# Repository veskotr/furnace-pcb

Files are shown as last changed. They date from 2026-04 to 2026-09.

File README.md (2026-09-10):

# Furnace Controller PCB

Hardware revisions are kept side by side:

- `Furnace_Controller_V1/` — the original 99-footprint design, last produced in June 2026.
- `Furnace_Controller_V2/` — the active 125-footprint revision, including the expanded functional-sheet hierarchy and TI footprint corrections.

Open the `Furnace_Controller.kicad_pro` inside the revision you intend to edit.
Shared third-party symbols and footprints live in `libraries/Symbols/`; each revision's
library-table files resolve these assets using project-relative paths.

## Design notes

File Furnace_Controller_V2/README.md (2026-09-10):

# Furnace Controller V2

Open `Furnace_Controller.kicad_pro` as the project entry point.

The root schematic is the system sheet. Functional sheets are named by their
role (power conversion, communications, supervision, I/O, Ethernet, and relay
drivers). Repeated relay and 3.3 V regulator channels intentionally share a
single child-sheet source.

Project-local TI symbols and footprints are declared in `sym-lib-table` and
`fp-lib-table`; their source files live in `../libraries/Symbols/`. Child
schematics live in `sheets/`; generated Gerbers and assembly outputs live in
`fabrication/`, while PDFs and 3D exports live in `documentation/`.

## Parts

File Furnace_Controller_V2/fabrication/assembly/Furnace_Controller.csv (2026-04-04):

Reference | Qty | Value | DNP | Exclude from BOM | Exclude from Board | Footprint | Datasheet
BZ1 | 1 | Buzzer |  |  |  | Buzzer_Beeper:Buzzer_15x7.5RM7.6 | ~
C1 | 1 | 220u |  |  |  | Capacitor_THT:CP_Radial_D12.5mm_P5.00mm | ~
C2,C5,C6,C7,C8,C9 | 6 | 100n |  |  |  | Capacitor_SMD:C_0805_2012Metric_Pad1.18x1.45mm_HandSolder | ~
C3 | 1 | 47u |  |  |  | Capacitor_THT:CP_Radial_D8.0mm_P2.50mm | ~
C4,C10 | 2 | 10u |  |  |  | Capacitor_THT:CP_Radial_D5.0mm_P2.00mm | ~
D1,D16 | 2 | 1N5822 |  |  |  | Diode_THT:D_DO-201AD_P15.24mm_Horizontal | http://www.vishay.com/docs/88526/1n5820.pdf
D2,D4,D7,D9,D19 | 5 | 1N4148 |  |  |  | Diode_THT:D_DO-35_SOD27_P7.62mm_Horizontal | https://assets.nexperia.com/documents/data-sheet/1N4148_1N4448.pdf
D3,D5,D6,D8,D10,D11,D12,D13,D14,D15 | 10 | LED |  |  |  | LED_SMD:LED_0805_2012Metric | ~
D17,D18 | 2 | SMAJ30CA |  |  |  | Diode_SMD:D_SMA | https://www.littelfuse.com/media?itemid=75e32973-b177-4ee3-a0ff-cedaf1abdb93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
F2 | 1 | 3588 |  |  |  | MiniAutoFuse:3588 | https://www.keyelco.com/product-pdf.cfm?p=311
H1,H2,H3,H4 | 4 | MountingHole |  | Excluded from BOM |  | MountingHole:MountingHole_5.3mm_M5 | ~
J1 | 1 | Power In Treminal |  |  |  | TerminalBlock:TerminalBlock_MaiXu_MX126-5.0-02P_1x02_P5.00mm | ~
J3 | 1 | Relay Terminal |  |  |  | TerminalBlock:TerminalBlock_MaiXu_MX126-5.0-09P_1x09_P5.00mm | ~
J4 | 1 | HMD Terminal |  |  |  | TerminalBlock:TerminalBlock_MaiXu_MX126-5.0-04P_1x04_P5.00mm | ~
J5 | 1 | RS-485 Terminal |  |  |  | TerminalBlock:TerminalBlock_MaiXu_MX126-5.0-04P_1x04_P5.00mm | ~
L1 | 1 | 33u |  |  |  | Coil:SRR1260-150M | ~
Q1,Q2,Q3,Q4 | 4 | IRLZ44N |  |  |  | Package_TO_SOT_THT:TO-220-3_Vertical | http://www.irf.com/product-info/datasheets/data/irlz44n.pdf
Q5 | 1 | 2n2222 |  |  |  | Package_TO_SOT_THT:TO-92_Inline | https://diotec.com/tl_files/diotec/files/pdf/datasheets/bc337.pdf
R1,R3 | 2 | 10k |  |  |  | Resistor_SMD:R_0805_2012Metric_Pad1.20x1.40mm_HandSolder | ~
R4,R7,R10,R14 | 4 | 100 |  |  |  | Resistor_SMD:R_0805_2012Metric_Pad1.20x1.40mm_HandSolder | ~
R5,R8,R11,R15 | 4 | 47k |  |  |  | Resistor_SMD:R_0805_2012Metric_Pad1.20x1.40mm_HandSolder | ~
R6,R9,R12,R13,R18,R19,R21,R22 | 8 | 68 |  |  |  | Resistor_SMD:R_0805_2012Metric_Pad1.20x1.40mm_HandSolder | ~
R16,R17 | 2 | 15 |  |  |  | Resistor_SMD:R_0805_2012Metric_Pad1.20x1.40mm_HandSolder | ~
R20,R23 | 2 | 330 |  |  |  | Resistor_SMD:R_0805_2012Metric_Pad1.20x1.40mm_HandSolder | ~
R24 | 1 | 120 |  |  |  | Resistor_SMD:R_0805_2012Metric_Pad1.20x1.40mm_HandSolder | ~
R25 | 1 | 1k |  |  |  | Resistor_SMD:R_0805_2012Metric_Pad1.20x1.40mm_HandSolder | ~
TP1,TP3,TP4,TP6 | 4 | HR_TP |  |  |  | TestPoint:TestPoint_Pad_D1.5mm | ~
TP2 | 1 | PGND_TP |  |  |  | TestPoint:TestPoint_Pad_D1.5mm | ~
TP5,TP7,TP8,TP9,TP11 | 5 | LGND_TP |  |  |  | TestPoint:TestPoint_Pad_D1.5mm | ~
TP12 | 1 | RSB_TP |  |  |  | TestPoint:TestPoint_Pad_D1.5mm | ~
TP13 | 1 | RSA_TP |  |  |  | TestPoint:TestPoint_Pad_D1.5mm | ~
TP14,TP20 | 2 | 5V_TP |  |  |  | TestPoint:TestPoint_Pad_D1.5mm | ~
TP15 | 1 | U2RX_TP |  |  |  | TestPoint:TestPoint_Pad_D1.5mm | ~
TP16 | 1 | U2TX_TP |  |  |  | TestPoint:TestPoint_Pad_D1.5mm | ~
TP18 | 1 | RS_DIR |  |  |  | TestPoint:TestPoint_Pad_D1.5mm | ~
TP19,TP21 | 2 | 3V3_TP |  |  |  | TestPoint:TestPoint_Pad_D1.5mm | ~
TP22 | 1 | U1TX_TP |  |  |  | TestPoint:TestPoint_Pad_D1.5mm | ~
TP23 | 1 | U1RX_TP |  |  |  | TestPoint:TestPoint_Pad_D1.5mm | ~
TP24 | 1 | HMDTX_TP |  |  |  | TestPoint:TestPoint_Pad_D1.5mm | ~
TP25 | 1 | HMDRX_TP |  |  |  | TestPoint:TestPoint_Pad_D1.5mm | ~
TP26 | 1 | 24V_TP |  |  |  | TestPoint:TestPoint_Pad_D1.5mm | ~
U1 | 1 | ~ |  |  |  | Custom_Footprints:ESP32_DevKitc_V4
U2 | 1 | LM2596S-5 |  |  |  | Package_TO_SOT_SMD:TO-263-5_TabPin3 | http://www.ti.com/lit/ds/symlink/lm2596.pdf
U3 | 1 | THVD2450DR |  |  |  | THVD:SOIC127P600X175-8N | https://www.ti.com/lit/gpn/thvd2450
U4,U5 | 2 | TXU0101DBVR |  |  |  | TXU:SOT95P280X145-6N | TXU0101DBVR
U6 | 1 | TVS3300DRV |  |  |  | Package_SON:WSON-6-1EP_2x2mm_P0.65mm_EP1x1.6mm | http://www.ti.com/lit/ds/symlink/tvs3300.pdf

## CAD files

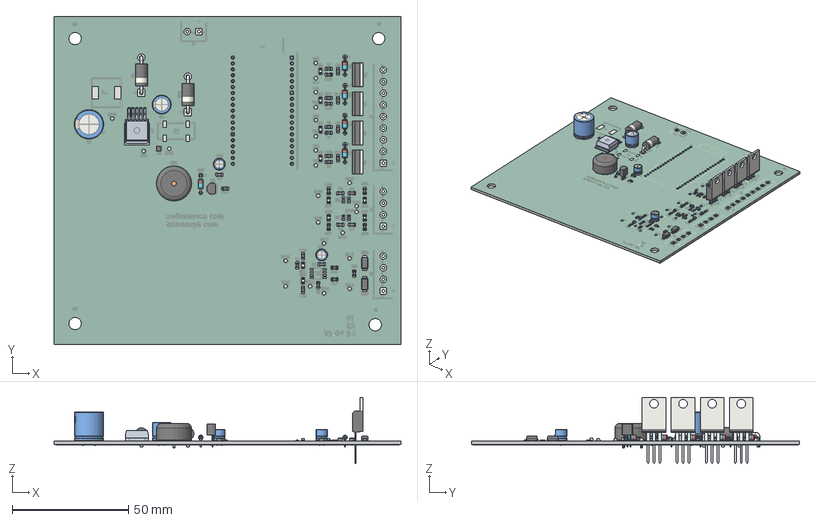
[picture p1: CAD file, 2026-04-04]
Furnace_Controller_V2/documentation/Furnace_Controller.step
149.0 x 141.0 x 28.5 mm
R_0805_2012Metric x 24
C_0805_2012Metric x 6
D_DO-35_SOD27_P7.62mm_Horizontal x 5
LED_0805_2012Metric x 10
TO-220-3_Vertical x 4
CP_Radial_D12.5mm_P5.00mm
D_SMA x 2
D_DO-201AD_P15.24mm_Horizontal x 2
CP_Radial_D8.0mm_P2.50mm
WSON-6-1EP_2x2mm_P0.65mm_EP1x1.6mm
CP_Radial_D5.0mm_P2.00mm x 2
TO-92_Inline
Buzzer_15x7.5RM7.6
Furnace_Controller 1.59.1
Furnace_Controller_copper
Furnace_Controller_pad
Furnace_Controller_via
Furnace_Controller_silkscreen
Furnace_Controller_soldermask x 2
Furnace_Controller_PCB

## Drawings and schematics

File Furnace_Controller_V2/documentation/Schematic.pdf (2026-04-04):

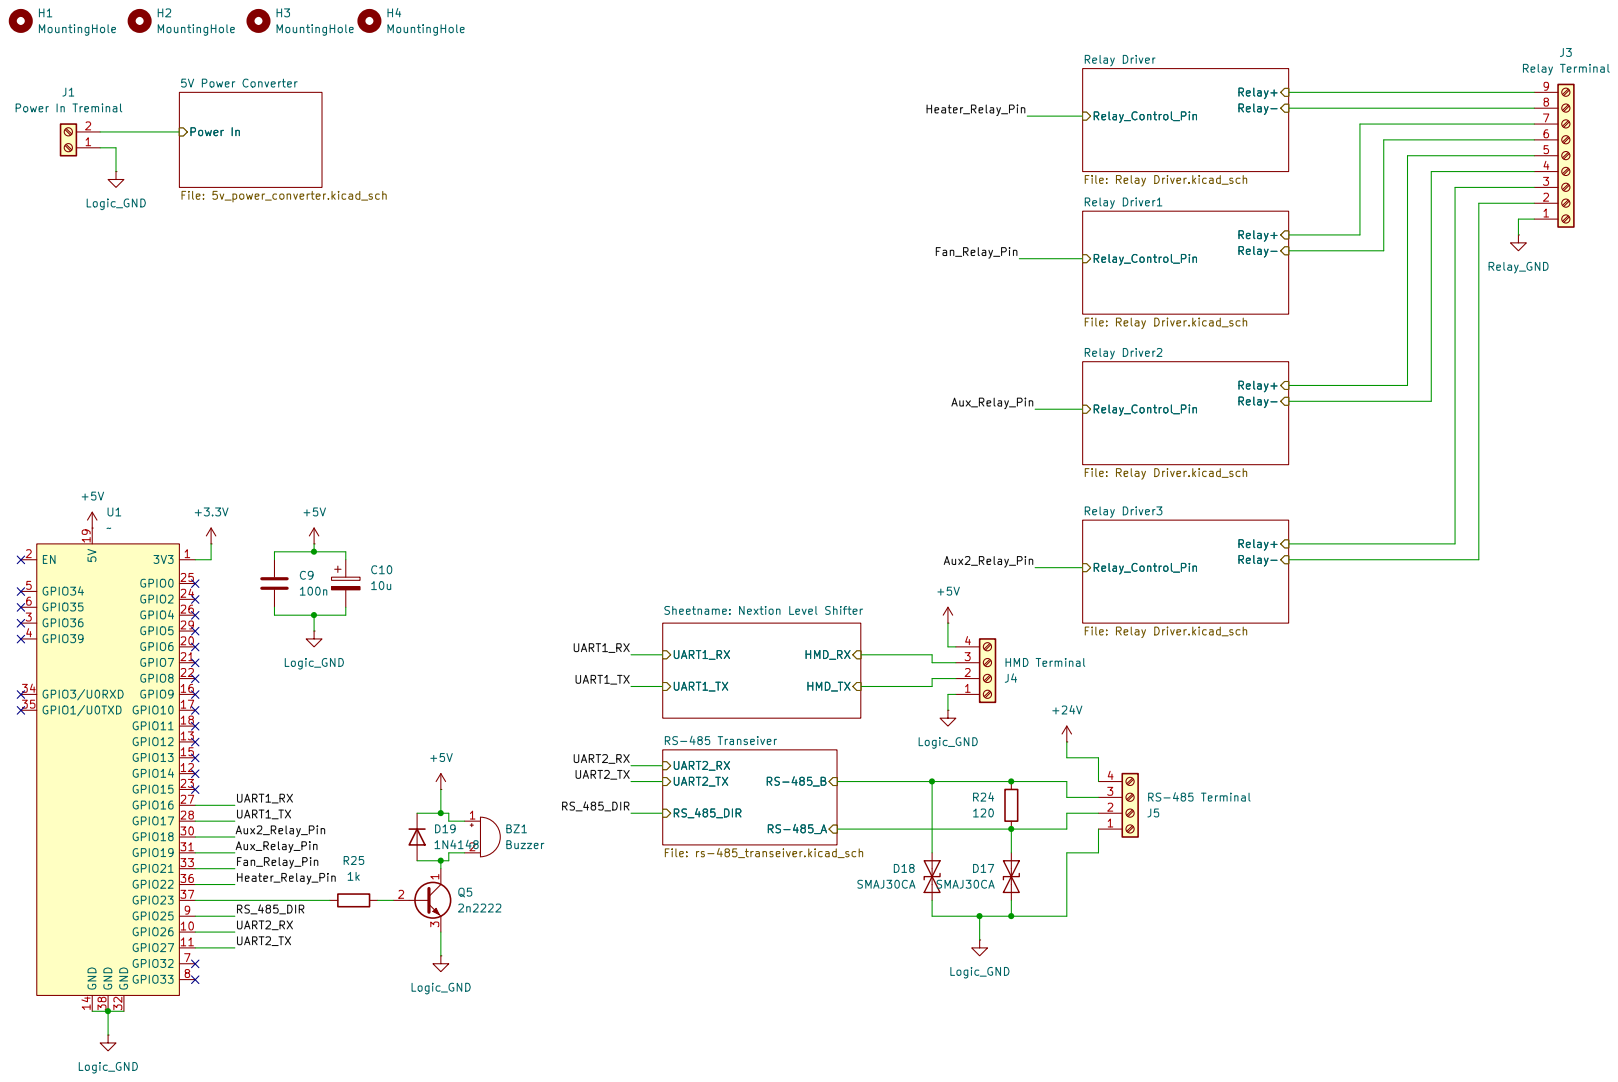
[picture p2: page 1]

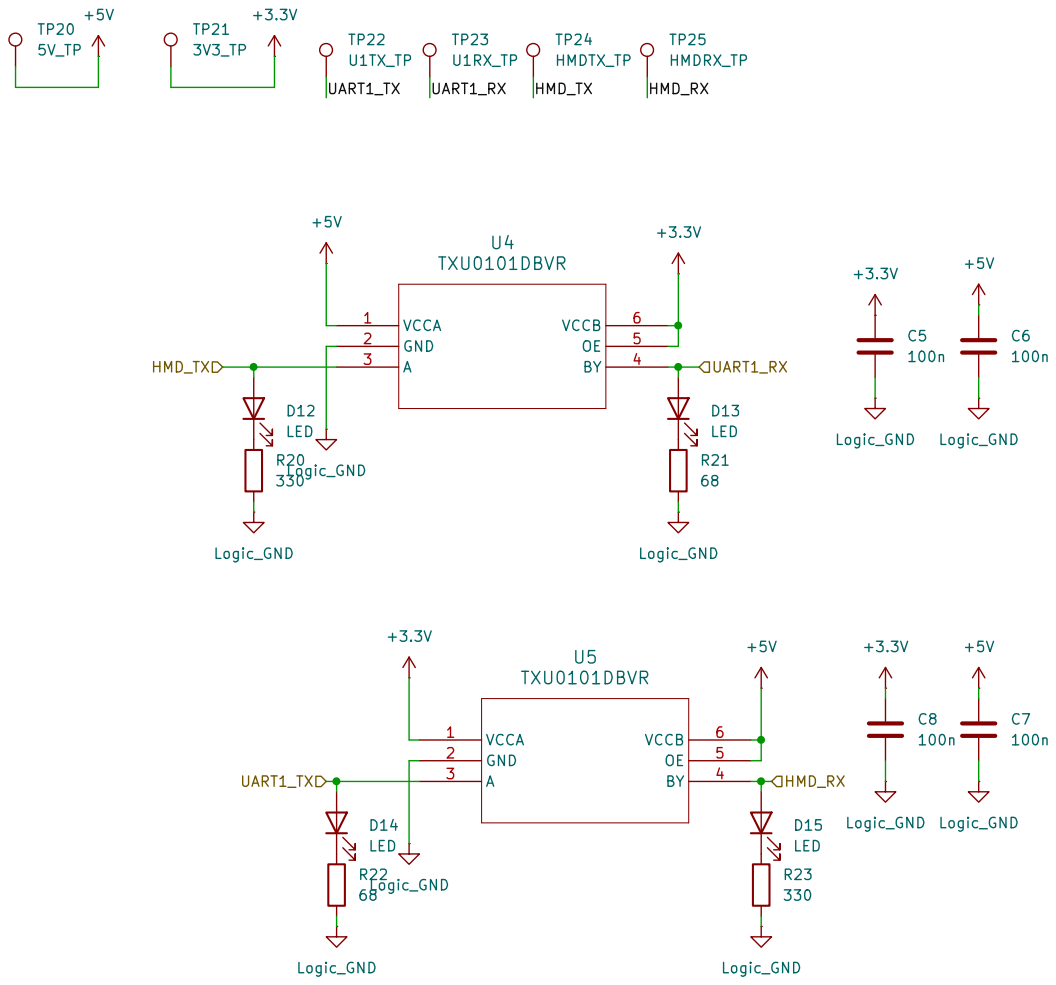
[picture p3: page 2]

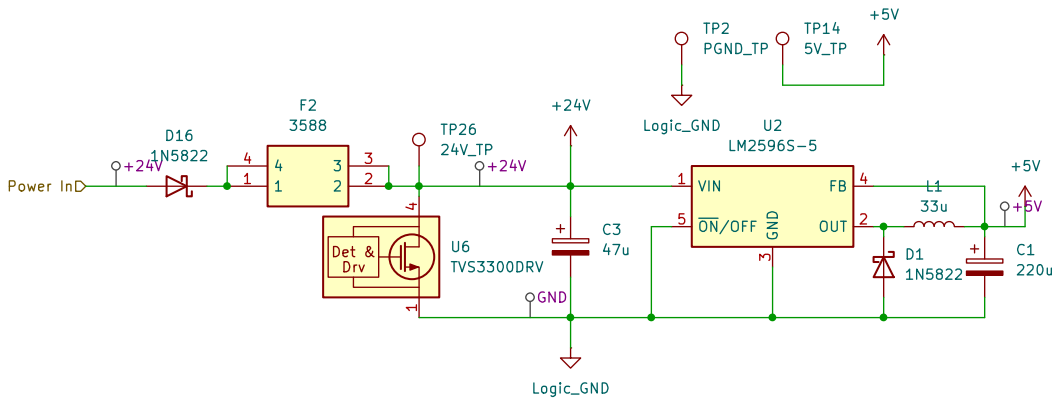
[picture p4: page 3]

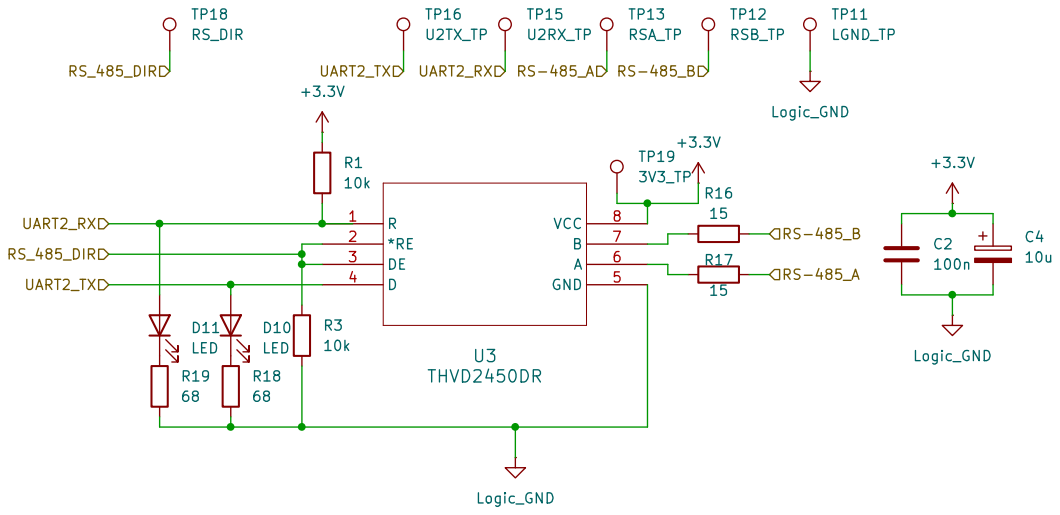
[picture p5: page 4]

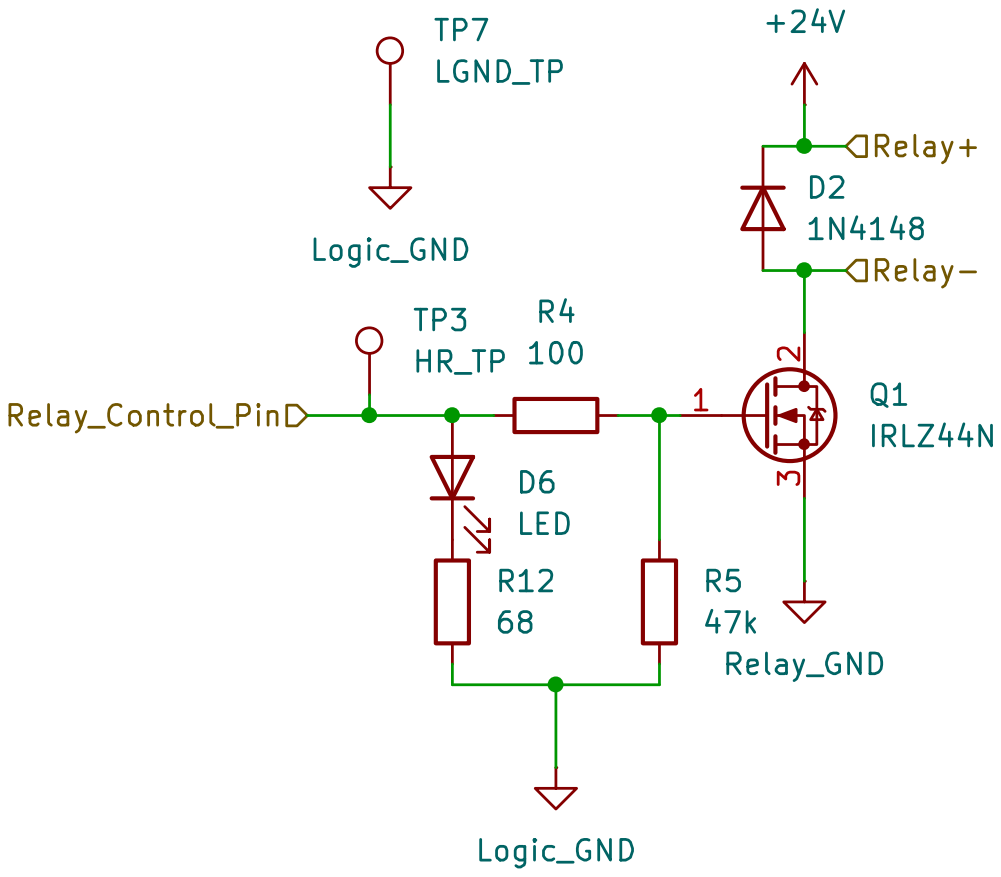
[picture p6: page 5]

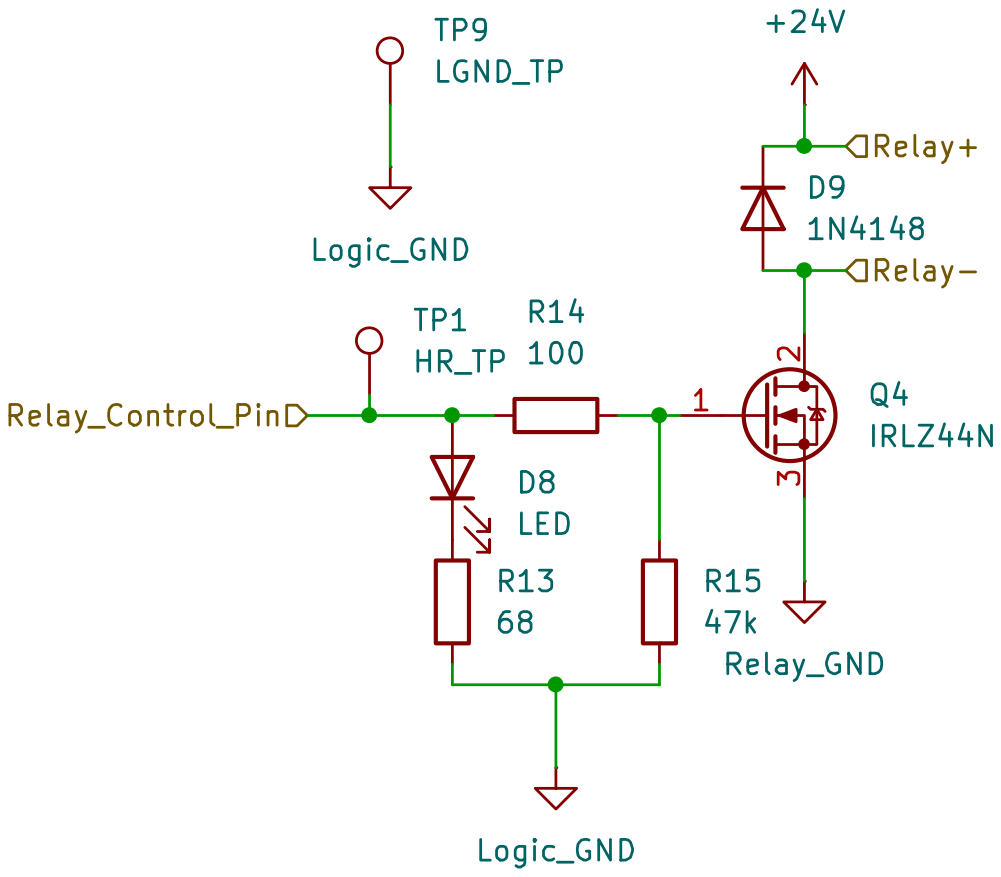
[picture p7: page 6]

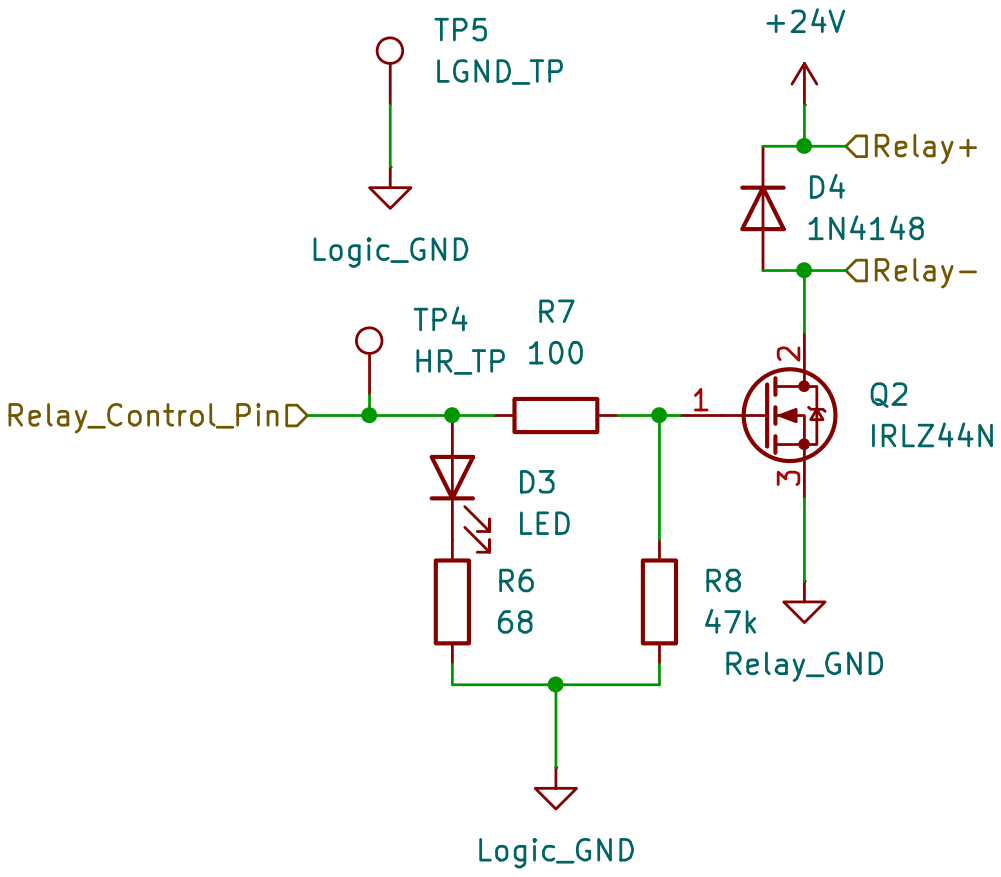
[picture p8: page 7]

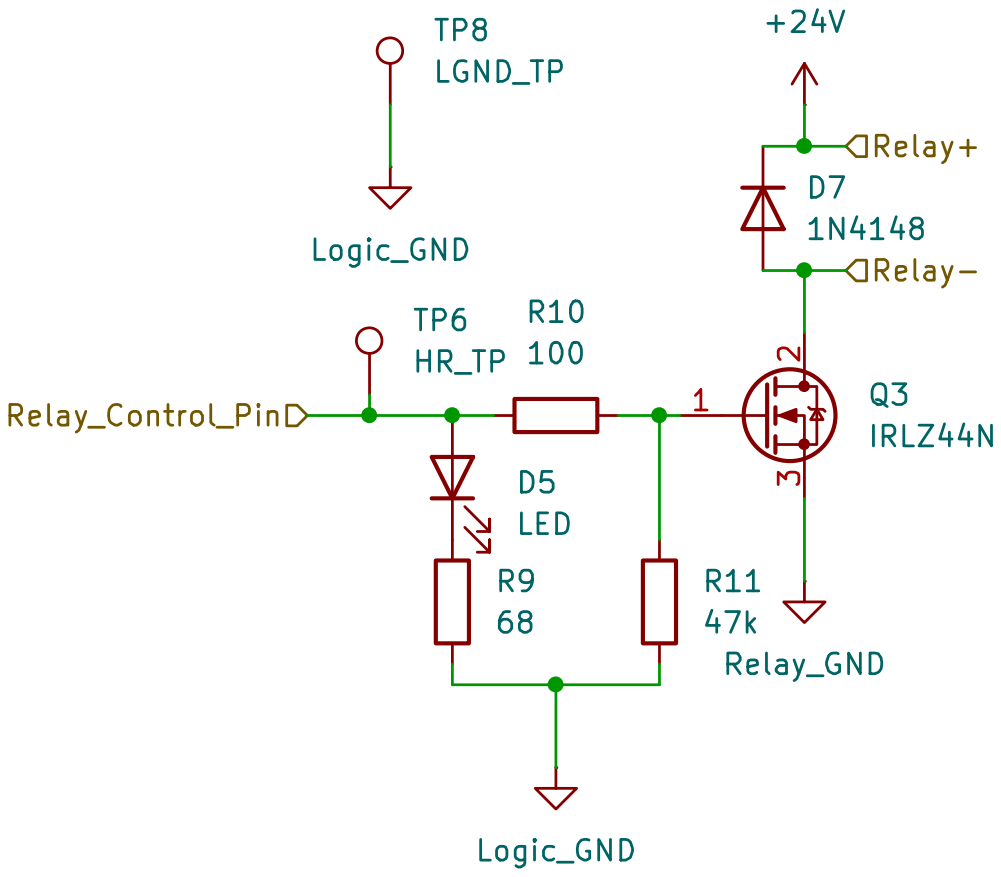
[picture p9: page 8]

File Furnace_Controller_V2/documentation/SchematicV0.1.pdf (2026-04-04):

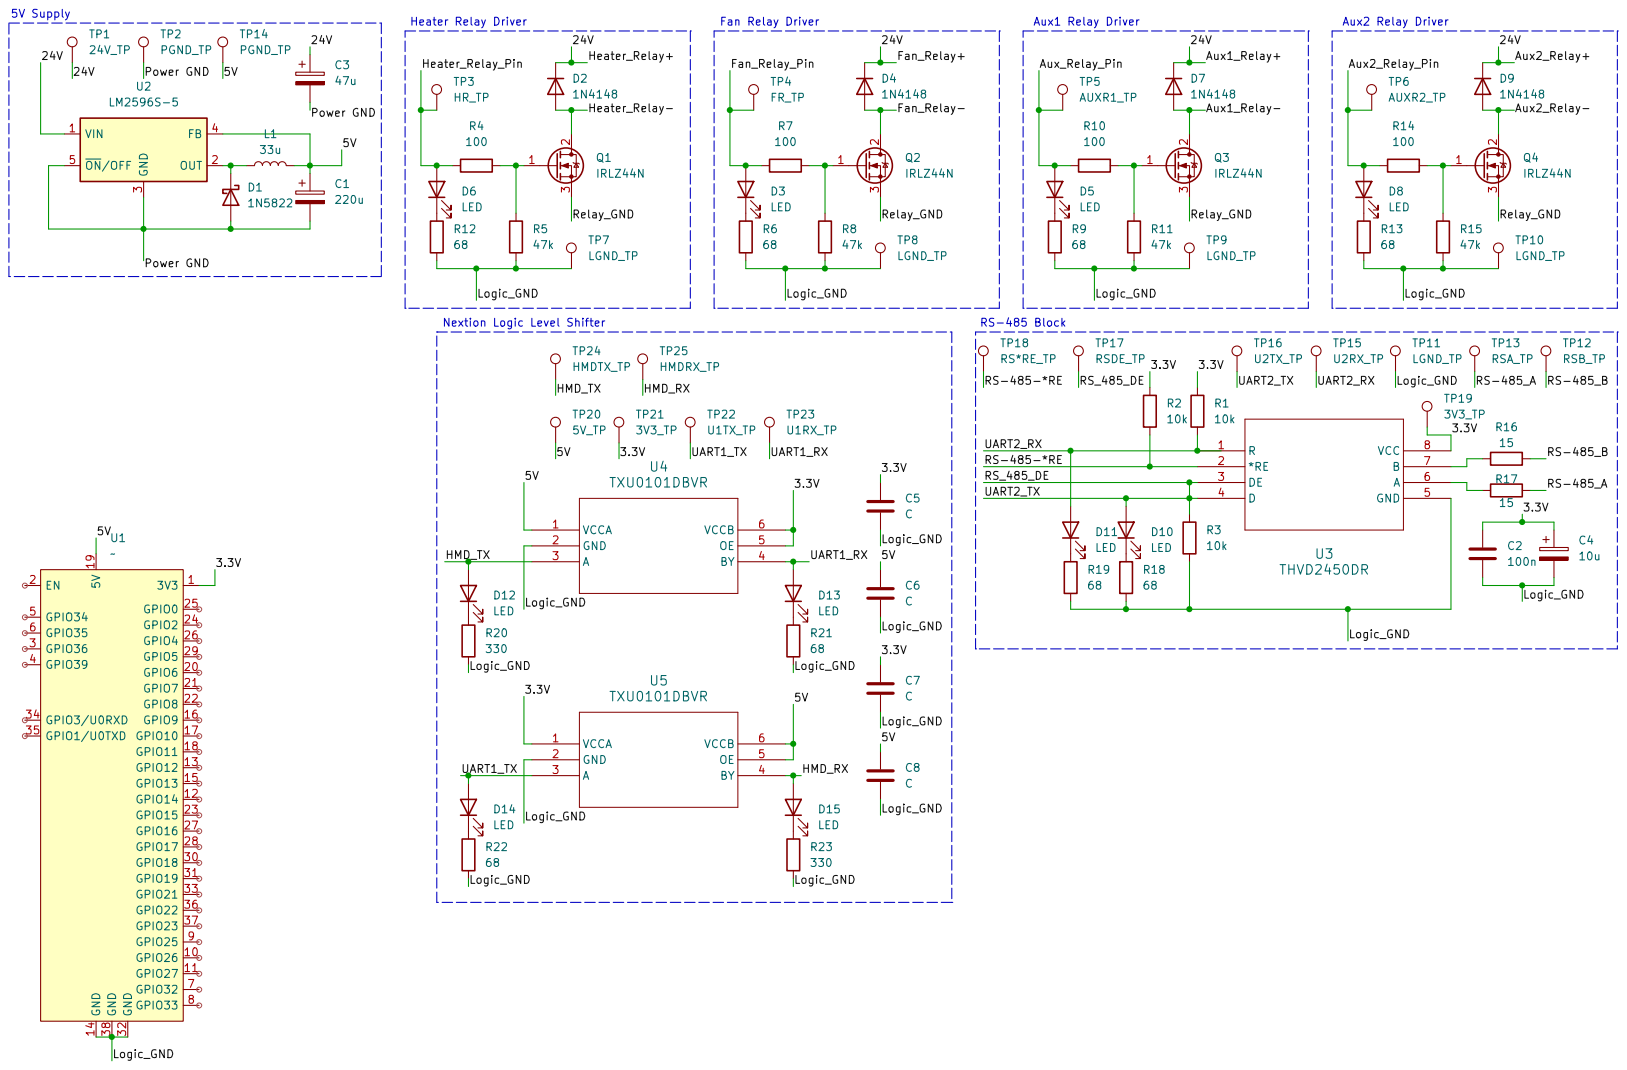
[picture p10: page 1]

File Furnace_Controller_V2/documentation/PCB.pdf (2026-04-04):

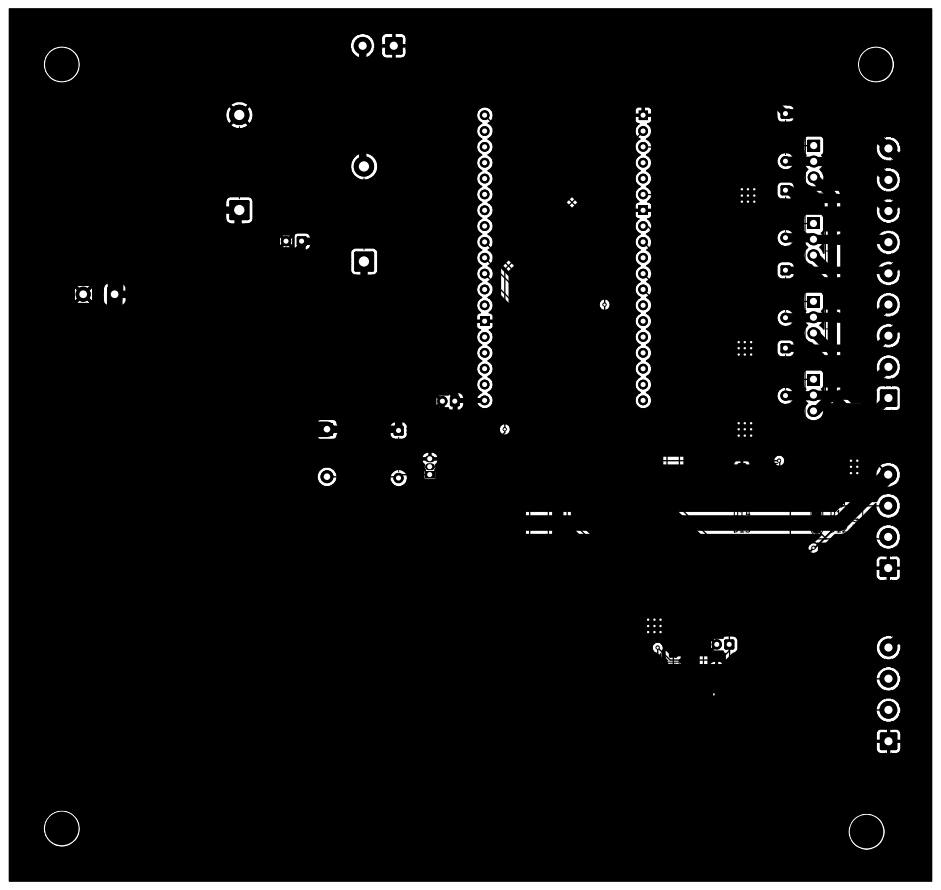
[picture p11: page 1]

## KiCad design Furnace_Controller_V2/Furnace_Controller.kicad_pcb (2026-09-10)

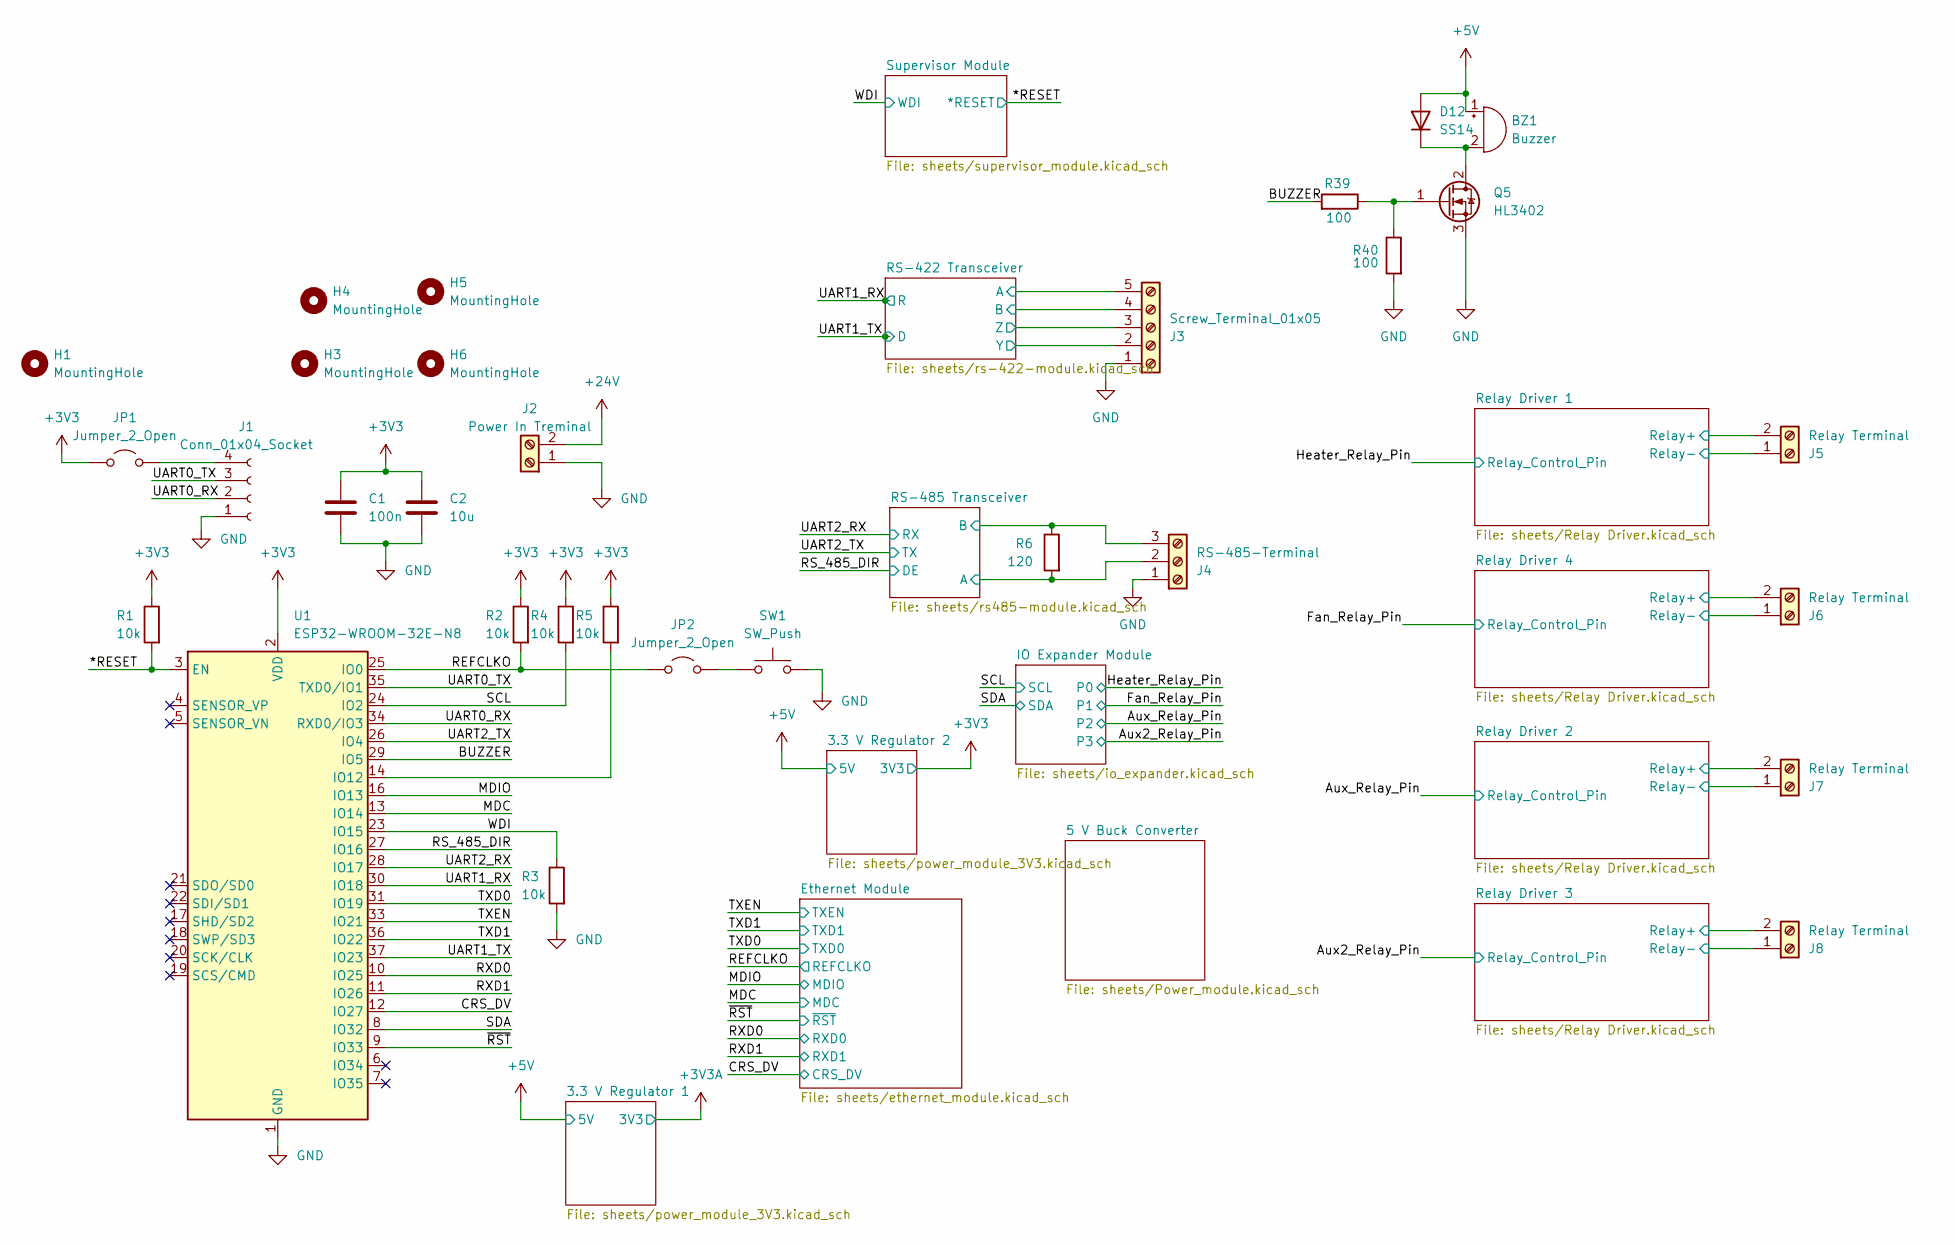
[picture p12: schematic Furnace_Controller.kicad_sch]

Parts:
BZ1: Buzzer; Buzzer_15x7.5RM7.6
C1: 100n; C_0603_1608Metric
C2: 10u; C_0805_2012Metric
D12: SS14; D_SOD-123
H1, H3, H4, H6: MountingHole; MountingHole_3.2mm_M3
H5: MountingHole; MountingHole_2.2mm_M2
J1: Conn_01x04_Socket; PinHeader_1x04_P2.54mm_Vertical
J2: Power In Treminal; PhoenixContact_MC_1,5_2-G-3.5_1x02_P3.50mm_Horizontal
J3: Screw_Terminal_01x05; PhoenixContact_MC_1,5_5-G-3.5_1x05_P3.50mm_Horizontal
J4: RS-485-Terminal; PhoenixContact_MC_1,5_3-G-3.5_1x03_P3.50mm_Horizontal
J5, J6, J7, J8: Relay Terminal; PhoenixContact_MC_1,5_2-G-3.5_1x02_P3.50mm_Horizontal
JP1, JP2: Jumper_2_Open; TestPoint_2Pads_Pitch2.54mm_Drill0.8mm
Q5: HL3402; Q_SOT-23
R1, R2, R3, R4, R5: 10k; R_0603_1608Metric
R6: 120; R_0603_1608Metric
R39, R40: 100; R_0603_1608Metric
SW1: SW_Push; SW_PUSH_6mm_H4.3mm
U1: ESP32-WROOM-32E-N8; ESP32-WROOM-32

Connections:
+3V3: C1.1, C2.1, JP1.1 (A), R1.1, R2.1, R4.1, R5.1, U1.2 (VDD); also elsewhere on the board
+5V: BZ1.1 (+), D12.2 (A); also elsewhere on the board
+24V: J2.2, J5.2, J6.2, J7.2, J8.2; also elsewhere on the board
/*RESET: R1.2, U1.3 (EN); also elsewhere on the board
/BUZZER: R39.2, U1.29 (IO5)
/CRS_DV: U1.12 (IO27); also elsewhere on the board
/MDC: U1.13 (IO14); also elsewhere on the board
/MDIO: U1.16 (IO13); also elsewhere on the board
/REFCLKO: JP2.1 (A), R2.2, U1.25 (IO0); also elsewhere on the board
/RS-422-module/A: J3.5; also elsewhere on the board
/RS-422-module/B: J3.4; also elsewhere on the board
/RS-422-module/Y: J3.2; also elsewhere on the board
/RS-422-module/Z: J3.3; also elsewhere on the board
/RS_485_DIR: U1.27 (IO16); also elsewhere on the board
/RXD0: U1.10 (IO25); also elsewhere on the board
/RXD1: U1.11 (IO26); also elsewhere on the board
/Relay Driver1/Relay-: J6.1; also elsewhere on the board
/Relay Driver2/Relay-: J7.1; also elsewhere on the board
/Relay Driver3/Relay-: J8.1; also elsewhere on the board
/Relay Driver/Relay-: J5.1; also elsewhere on the board
/SCL: R4.2, U1.24 (IO2); also elsewhere on the board
/SDA: U1.8 (IO32); also elsewhere on the board
/TXD0: U1.31 (IO19); also elsewhere on the board
/TXD1: U1.36 (IO22); also elsewhere on the board
/TXEN: U1.33 (IO21); also elsewhere on the board
/UART0_RX: J1.2, U1.34 (RXD0/IO3)
/UART0_TX: J1.3, U1.35 (TXD0/IO1)
/UART1_RX: U1.30 (IO18); also elsewhere on the board
/UART1_TX: U1.37 (IO23); also elsewhere on the board
/UART2_RX: U1.28 (IO17); also elsewhere on the board
/UART2_TX: U1.26 (IO4); also elsewhere on the board
/WDI: R3.1, U1.23 (IO15); also elsewhere on the board
/rs485-module/A: J4.2, R6.2; also elsewhere on the board
/rs485-module/B: J4.3, R6.1; also elsewhere on the board
/~RST: U1.9 (IO33); also elsewhere on the board
GND: C1.2, C2.2, J1.1, J2.1, J3.1, J4.1, Q5.3 (S), R3.2, R40.2, SW1.2, U1.1 (GND), U1.15 (GND), U1.38 (GND), U1.39 (GND); also elsewhere on the board
unnamed: BZ1.2 (-), D12.1 (K), Q5.2 (D)
unnamed: J1.4, JP1.2 (B)
unnamed: JP2.2 (B), SW1.1
unnamed: Q5.1 (G), R39.1, R40.1
unnamed: R5.2, U1.14 (IO12)

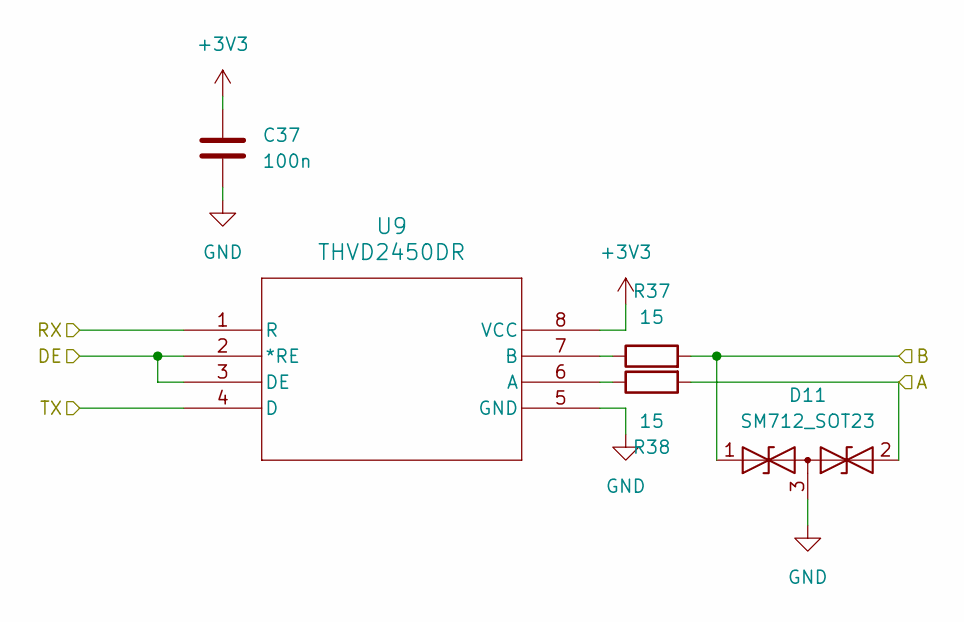
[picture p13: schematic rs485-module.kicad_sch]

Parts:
C37: 100n; C_0603_1608Metric
D11: SM712_SOT23; SOT-23
R37, R38: 15; R_0603_1608Metric
U9: THVD2450DR; SOIC-8_3.9x4.9mm_P1.27mm

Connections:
+3V3: C37.1, U9.8 (VCC); also elsewhere on the board
/RS_485_DIR: U9.2 (*RE), U9.3 (DE); also elsewhere on the board
/UART2_RX: U9.1 (R); also elsewhere on the board
/UART2_TX: U9.4 (D); also elsewhere on the board
/rs485-module/A: D11.2 (A2), R38.2; also elsewhere on the board
/rs485-module/B: D11.1 (A1), R37.2; also elsewhere on the board
GND: C37.2, D11.3 (common), U9.5 (GND); also elsewhere on the board
unnamed: R38.1, U9.6 (A)
unnamed: R37.1, U9.7 (B)

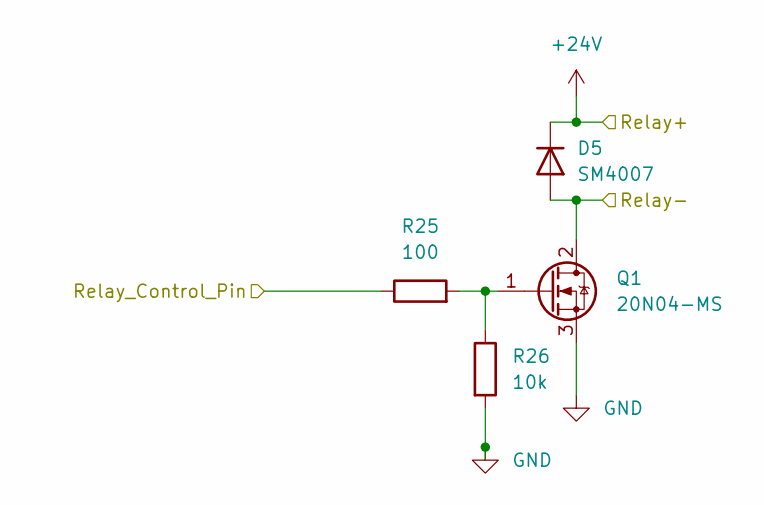
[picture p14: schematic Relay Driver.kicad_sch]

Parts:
D5: SM4007; D_SOD-123
Q1: 20N04-MS; Q_SOT-89
R25: 100; R_0603_1608Metric
R26: 10k; R_0603_1608Metric

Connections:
+24V: D5.1 (K); also elsewhere on the board
/Heater_Relay_Pin: R25.1; also elsewhere on the board
/Relay Driver/Relay-: D5.2 (A), Q1.2 (D); also elsewhere on the board
GND: Q1.3 (S), R26.2; also elsewhere on the board
unnamed: Q1.1 (G), R25.2, R26.1

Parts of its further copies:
D6, D7, D8: SM4007; D_SOD-123
Q2, Q3, Q4: 20N04-MS; Q_SOT-89
R27, R29, R31: 100; R_0603_1608Metric
R28, R30, R32: 10k; R_0603_1608Metric

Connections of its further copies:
+24V: D6.1 (K), D7.1 (K), D8.1 (K); also elsewhere on the board
/Aux2_Relay_Pin: R31.1; also elsewhere on the board
/Aux_Relay_Pin: R29.1; also elsewhere on the board
/Fan_Relay_Pin: R27.1; also elsewhere on the board
/Relay Driver1/Relay-: D6.2 (A), Q2.2 (D); also elsewhere on the board
/Relay Driver2/Relay-: D7.2 (A), Q3.2 (D); also elsewhere on the board
/Relay Driver3/Relay-: D8.2 (A), Q4.2 (D); also elsewhere on the board
GND: Q2.3 (S), Q3.3 (S), Q4.3 (S), R28.2, R30.2, R32.2; also elsewhere on the board
unnamed: Q2.1 (G), R27.2, R28.1
unnamed: Q3.1 (G), R29.2, R30.1
unnamed: Q4.1 (G), R31.2, R32.1

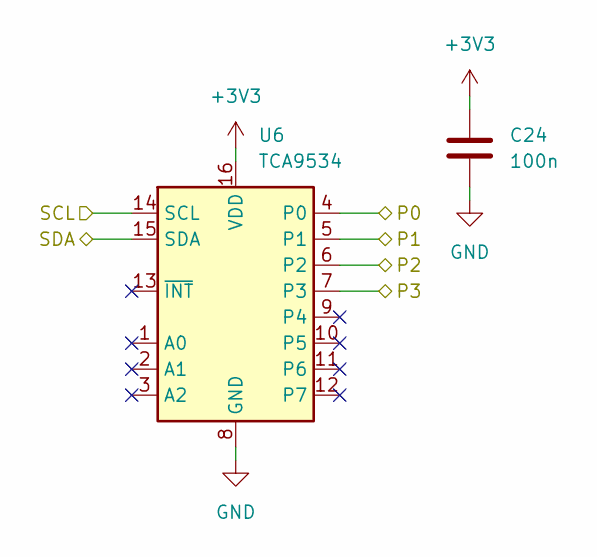
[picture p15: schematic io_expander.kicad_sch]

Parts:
C24: 100n; C_0603_1608Metric
U6: TCA9534; TSSOP-16_4.4x5mm_P0.65mm

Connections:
+3V3: C24.1, U6.16 (VDD); also elsewhere on the board
/Aux2_Relay_Pin: U6.7 (P3); also elsewhere on the board
/Aux_Relay_Pin: U6.6 (P2); also elsewhere on the board
/Fan_Relay_Pin: U6.5 (P1); also elsewhere on the board
/Heater_Relay_Pin: U6.4 (P0); also elsewhere on the board
/SCL: U6.14 (SCL); also elsewhere on the board
/SDA: U6.15 (SDA); also elsewhere on the board
GND: C24.2, U6.8 (GND); also elsewhere on the board

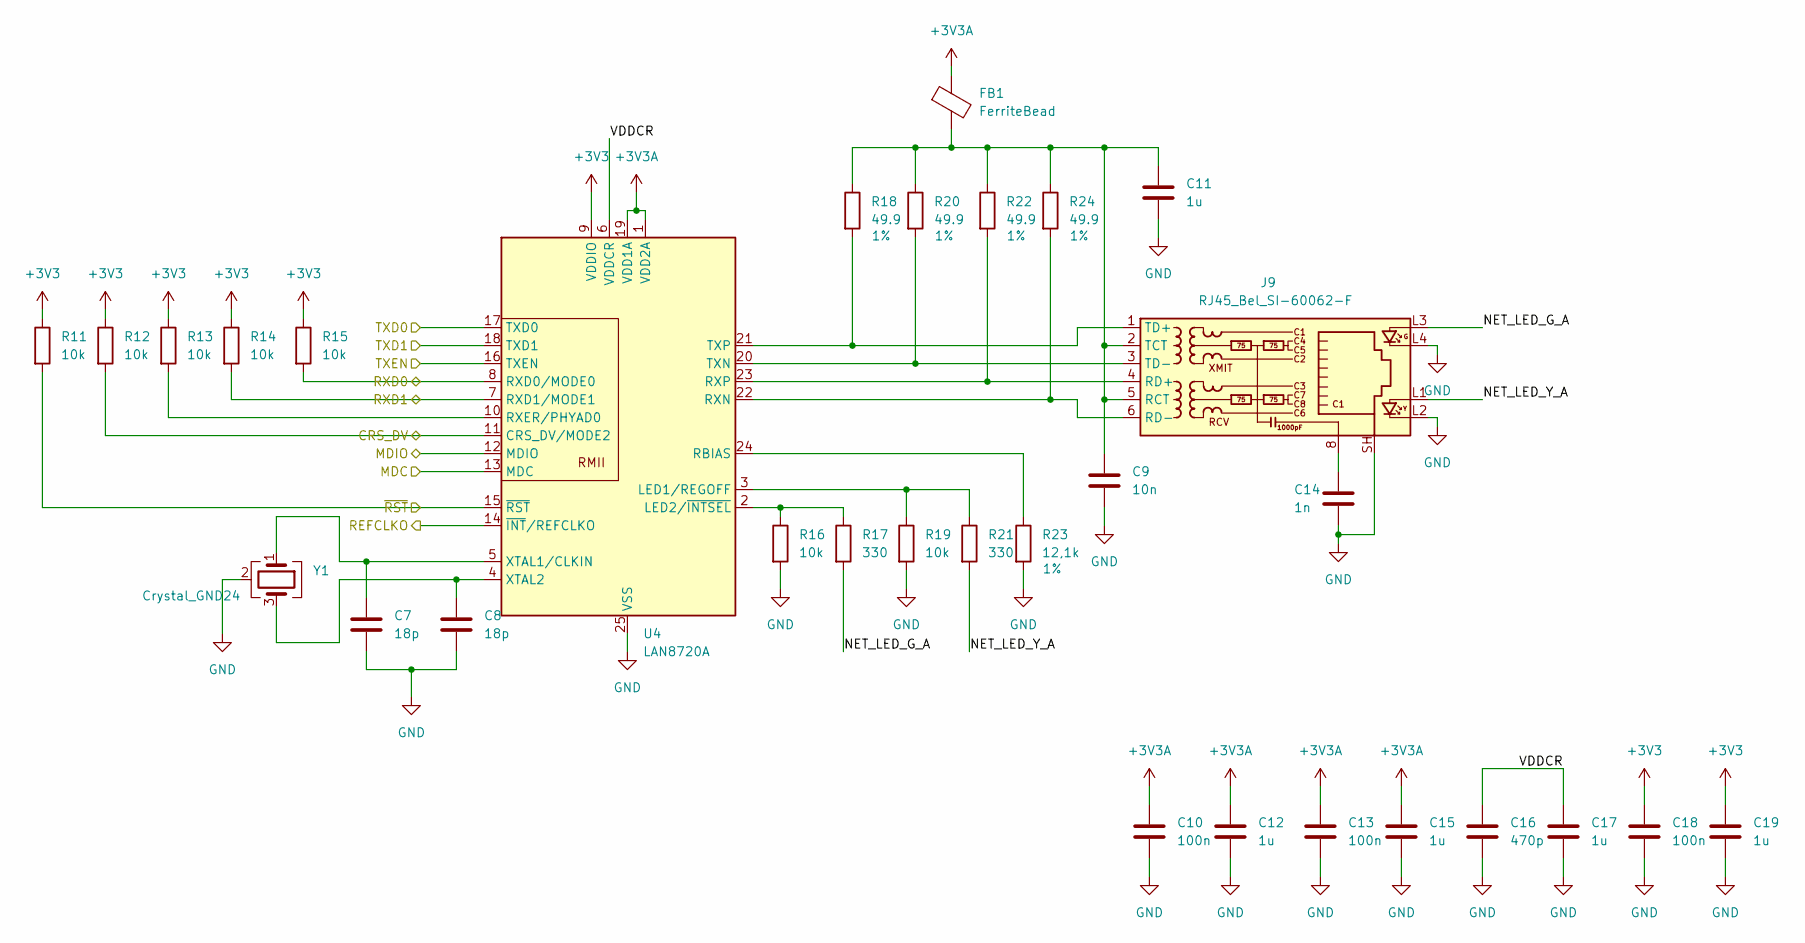
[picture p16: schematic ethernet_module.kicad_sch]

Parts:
C7, C8: 18p; C_0603_1608Metric
C9: 10n; C_0603_1608Metric
C10, C13, C18: 100n; C_0603_1608Metric
C11, C12, C15, C17, C19: 1u; C_0603_1608Metric
C14: 1n; C_1808_4520Metric
C16: 470p; C_0603_1608Metric
FB1: FerriteBead; L_0603_1608Metric
J9: RJ45_Bel_SI-60062-F
R11, R12, R13, R14, R15, R16, R19: 10k; R_0603_1608Metric
R17, R21: 330; R_0603_1608Metric
R18, R20, R22, R24: 49.9; R_0603_1608Metric
R23: 12,1k; R_0603_1608Metric
U4: LAN8720A; VQFN-24-1EP_4x4mm_P0.5mm_EP2.5x2.5mm_ThermalVias
Y1: Crystal_GND24; Crystal_SMD_3225-4Pin_3.2x2.5mm

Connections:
+3V3: C18.1, C19.1, R11.1, R12.1, R13.1, R14.1, R15.1, U4.9 (VDDIO); also elsewhere on the board
+3V3A: C10.1, C12.1, C13.1, C15.1, FB1.1, U4.1 (VDD2A), U4.19 (VDD1A); also elsewhere on the board
/CRS_DV: R12.2, U4.11 (CRS_DV/MODE2); also elsewhere on the board
/Ethernet Module/NET_LED_G_A: J9.L3, R17.2
/Ethernet Module/NET_LED_Y_A: J9.L1, R21.2
/Ethernet Module/VDDCR: C16.1, C17.1, U4.6 (VDDCR)
/MDC: U4.13 (MDC); also elsewhere on the board
/MDIO: U4.12 (MDIO); also elsewhere on the board
/REFCLKO: U4.14 (~INT/REFCLKO); also elsewhere on the board
/RXD0: R15.2, U4.8 (RXD0/MODE0); also elsewhere on the board
/RXD1: R14.2, U4.7 (RXD1/MODE1); also elsewhere on the board
/TXD0: U4.17 (TXD0); also elsewhere on the board
/TXD1: U4.18 (TXD1); also elsewhere on the board
/TXEN: U4.16 (TXEN); also elsewhere on the board
/~RST: R11.2, U4.15 (~RST); also elsewhere on the board
GND: C7.1, C8.2, C9.2, C10.2, C11.2, C12.2, C13.2, C14.2, C15.2, C16.2, C17.2, C18.2, C19.2, J9.L2, J9.L4, J9.SH, R16.2, R19.2, R23.2, U4.25 (VSS), Y1.2 (G), Y1.4 (G); also elsewhere on the board
unnamed: C14.1, J9.8
unnamed: C9.1, C11.1, FB1.2, J9.2 (TCT), J9.5 (RCT), R18.1, R20.1, R22.1, R24.1
unnamed: J9.4 (RD+), R22.2, U4.23 (RXP)
unnamed: J9.6 (RD-), R24.2, U4.22 (RXN)
unnamed: J9.1 (TD+), R18.2, U4.21 (TXP)
unnamed: J9.3 (TD-), R20.2, U4.20 (TXN)
unnamed: R19.1, R21.1, U4.3 (LED1/REGOFF)
unnamed: R16.1, R17.1, U4.2 (LED2/~INTSEL)
unnamed: R23.1, U4.24 (RBIAS)
unnamed: R13.2, U4.10 (RXER/PHYAD0)
unnamed: C7.2, U4.5 (XTAL1/CLKIN), Y1.1
unnamed: C8.1, U4.4 (XTAL2), Y1.3

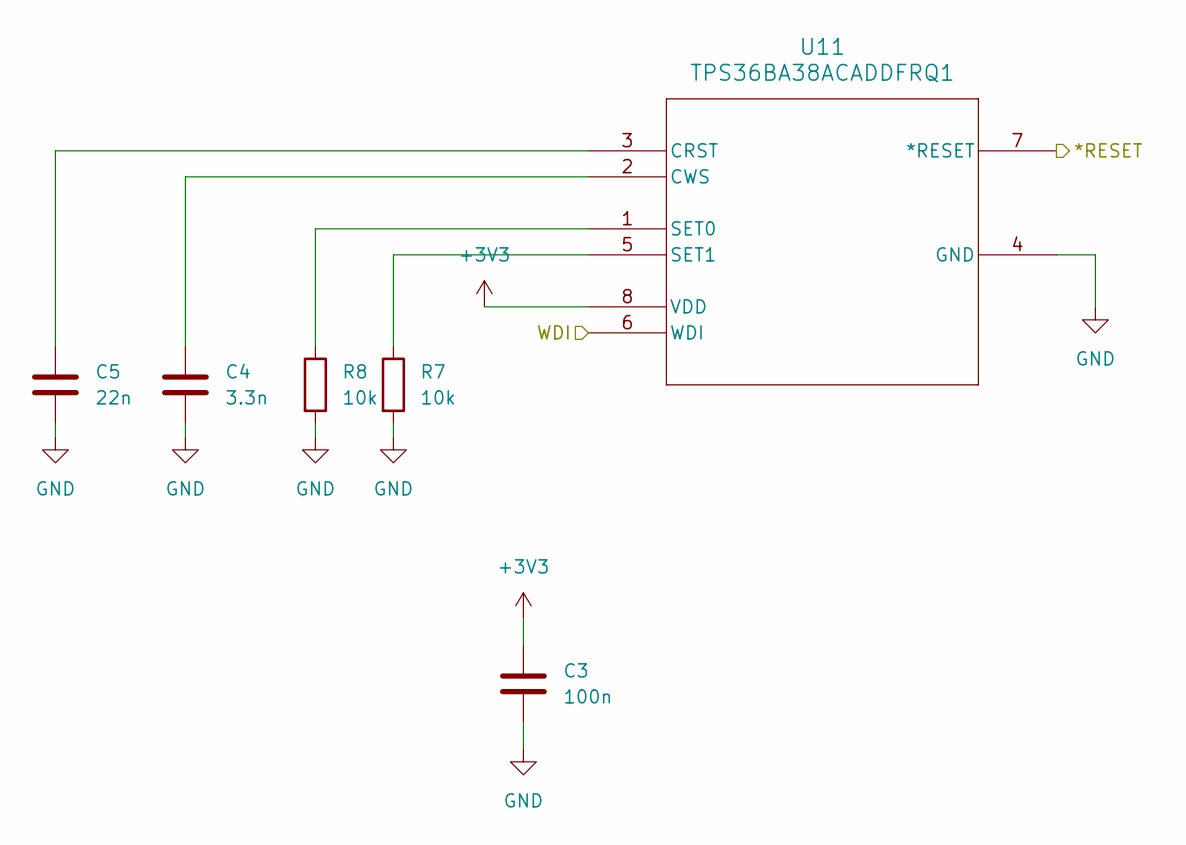
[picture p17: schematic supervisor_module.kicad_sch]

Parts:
C3: 100n; C_0603_1608Metric
C4: 3.3n; C_0603_1608Metric
C5: 22n; C_0603_1608Metric
R7, R8: 10k; R_0603_1608Metric
U11: TPS36BA38ACADDFRQ1; SOT-23-THIN-8_DDF_TEX

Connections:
+3V3: C3.1, U11.8 (VDD); also elsewhere on the board
/*RESET: U11.7 (*RESET); also elsewhere on the board
/WDI: U11.6 (WDI); also elsewhere on the board
GND: C3.2, C4.2, C5.2, R7.2, R8.2, U11.4 (GND); also elsewhere on the board
unnamed: C5.1, U11.3 (CRST)
unnamed: C4.1, U11.2 (CWS)
unnamed: R8.1, U11.1 (SET0)
unnamed: R7.1, U11.5 (SET1)

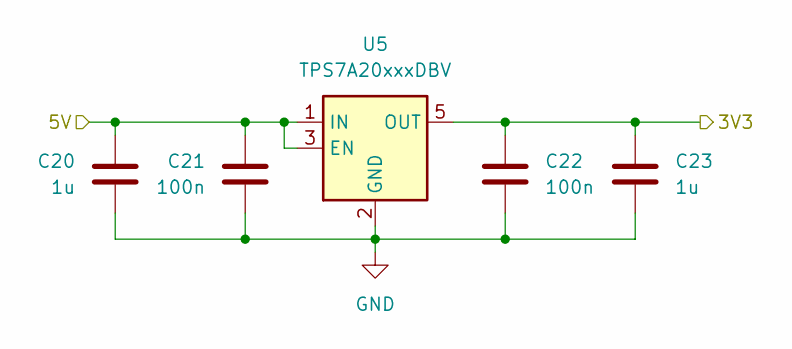
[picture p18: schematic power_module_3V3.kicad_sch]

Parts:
C20, C23: 1u; C_0603_1608Metric
C21, C22: 100n; C_0603_1608Metric
U5: TPS7A20xxxDBV; SOT-23-5

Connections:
+3V3A: C22.1, C23.1, U5.5 (OUT); also elsewhere on the board
+5V: C20.1, C21.1, U5.1 (IN), U5.3 (EN); also elsewhere on the board
GND: C20.2, C21.2, C22.2, C23.2, U5.2 (GND); also elsewhere on the board

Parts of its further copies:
C25, C28: 1u; C_0603_1608Metric
C26, C27: 100n; C_0603_1608Metric
U7: TPS7A20xxxDBV; SOT-23-5

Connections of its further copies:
+3V3: C27.1, C28.1, U7.5 (OUT); also elsewhere on the board
+5V: C25.1, C26.1, U7.1 (IN), U7.3 (EN); also elsewhere on the board
GND: C25.2, C26.2, C27.2, C28.2, U7.2 (GND); also elsewhere on the board

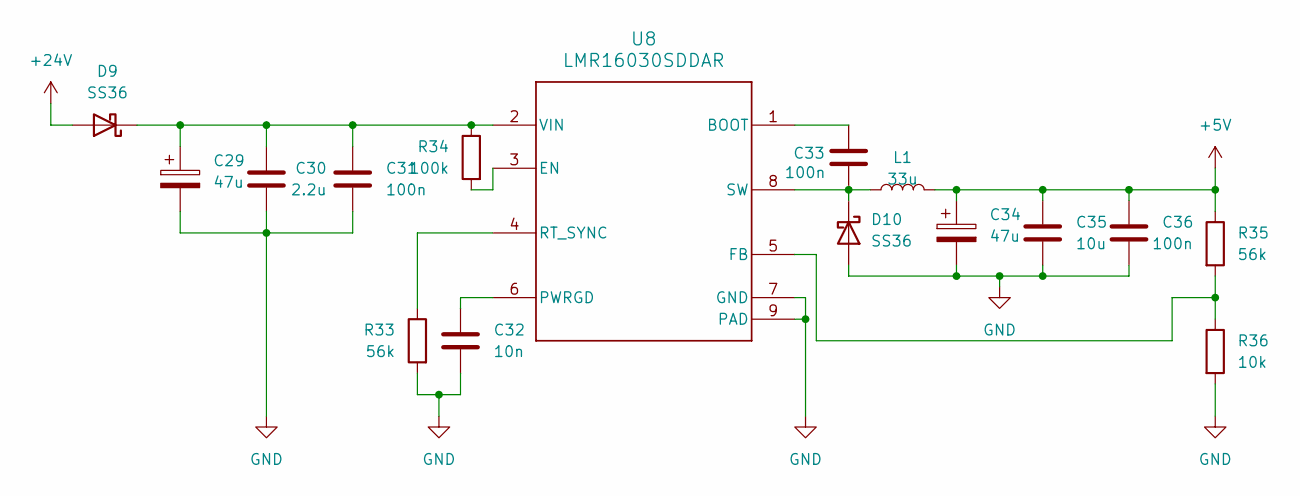
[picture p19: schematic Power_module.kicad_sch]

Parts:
C29, C34: 47u; CP_Radial_D6.3mm_P2.50mm
C30: 2.2u; C_0603_1608Metric
C31, C33, C36: 100n; C_0603_1608Metric
C32: 10n; C_0603_1608Metric
C35: 10u; C_0805_2012Metric
D9, D10: SS36; D_SMA
L1: 33u; L_6.3x6.3_H3
R33, R35: 56k; R_0603_1608Metric
R34: 100k; R_0603_1608Metric
R36: 10k; R_0603_1608Metric
U8: LMR16030SDDAR; SOIC-8-1EP_3.9x4.9mm_P1.27mm_EP2.29x3mm

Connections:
+5V: C34.1, C35.1, C36.1, L1.2, R35.1; also elsewhere on the board
+24V: D9.2 (A); also elsewhere on the board
GND: C29.2, C30.2, C31.2, C32.2, C34.2, C35.2, C36.2, D10.2 (A), R33.2, R36.2, U8.7 (GND), U8.9 (PAD); also elsewhere on the board
unnamed: C29.1, C30.1, C31.1, D9.1 (K), R34.1, U8.2 (VIN)
unnamed: C33.2, D10.1 (K), L1.1, U8.8 (SW)
unnamed: C33.1, U8.1 (BOOT)
unnamed: R34.2, U8.3 (EN)
unnamed: R35.2, R36.1, U8.5 (FB)
unnamed: C32.1, U8.6 (PWRGD)
unnamed: R33.1, U8.4 (RT_SYNC)

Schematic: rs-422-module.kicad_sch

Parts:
C38, C40: 100n; C_0603_1608Metric
C39, C41: 10u; C_0805_2012Metric
R41, R42, R43: 10k; R_0603_1608Metric
R44: 0; R_0603_1608Metric
U10: PTHVD2452VDR; SOIC-14_L8.7-W3.9-P1.27-LS6.0-BL

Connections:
+3V3: C38.1, C39.1, R42.1, R43.1, U10.1 (VIO); also elsewhere on the board
+5V: C40.1, C41.1, U10.14 (VCC); also elsewhere on the board
/RS-422-module/A: U10.12 (A); also elsewhere on the board
/RS-422-module/B: U10.11 (B); also elsewhere on the board
/RS-422-module/Y: U10.9 (Y); also elsewhere on the board
/RS-422-module/Z: U10.10 (Z); also elsewhere on the board
/UART1_RX: U10.2 (R); also elsewhere on the board
/UART1_TX: U10.5 (D); also elsewhere on the board
GND: C38.2, C39.2, C40.2, C41.2, R41.2, R44.2, U10.6 (GND); also elsewhere on the board
unnamed: R41.1, U10.3 (*RE)
unnamed: R42.2, U10.4 (DE)
unnamed: R43.2, R44.1, U10.8 (SLR)

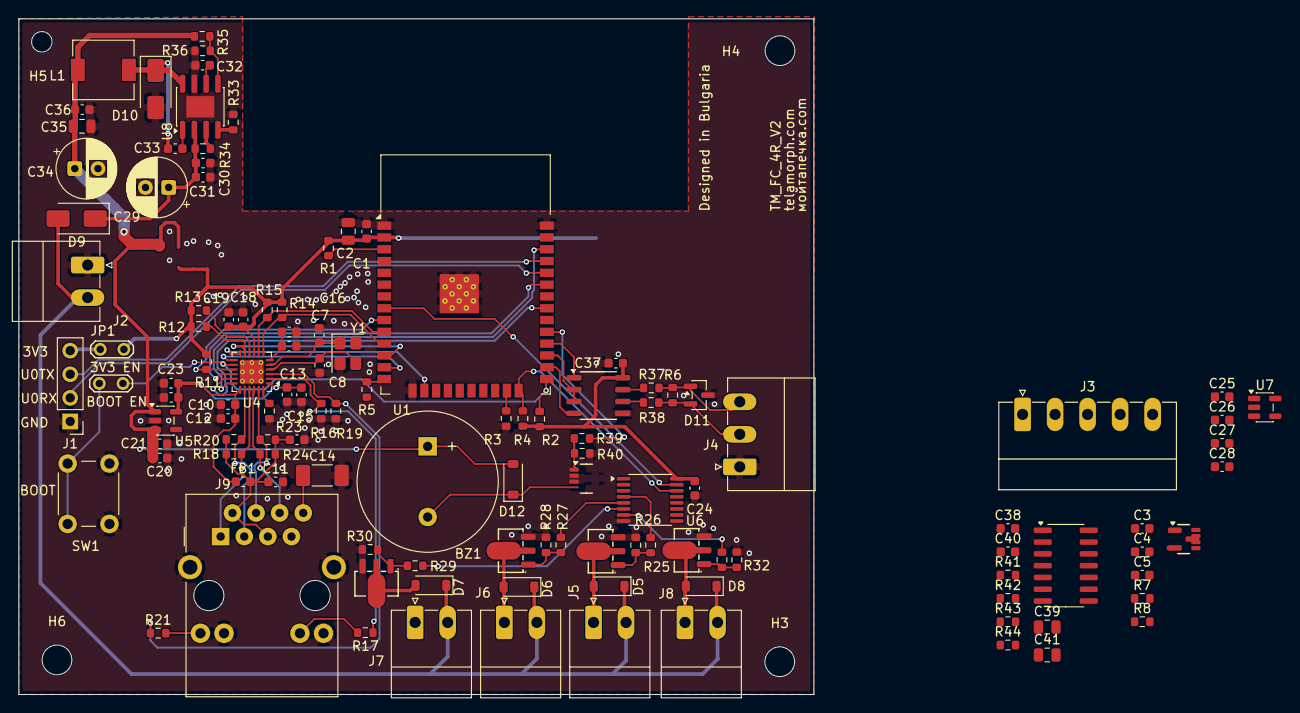
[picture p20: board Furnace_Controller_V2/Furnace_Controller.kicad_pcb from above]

Board: 4 copper layers, 85.6 x 72.7 mm, 125 parts (0 on the bottom side), 81 nets.

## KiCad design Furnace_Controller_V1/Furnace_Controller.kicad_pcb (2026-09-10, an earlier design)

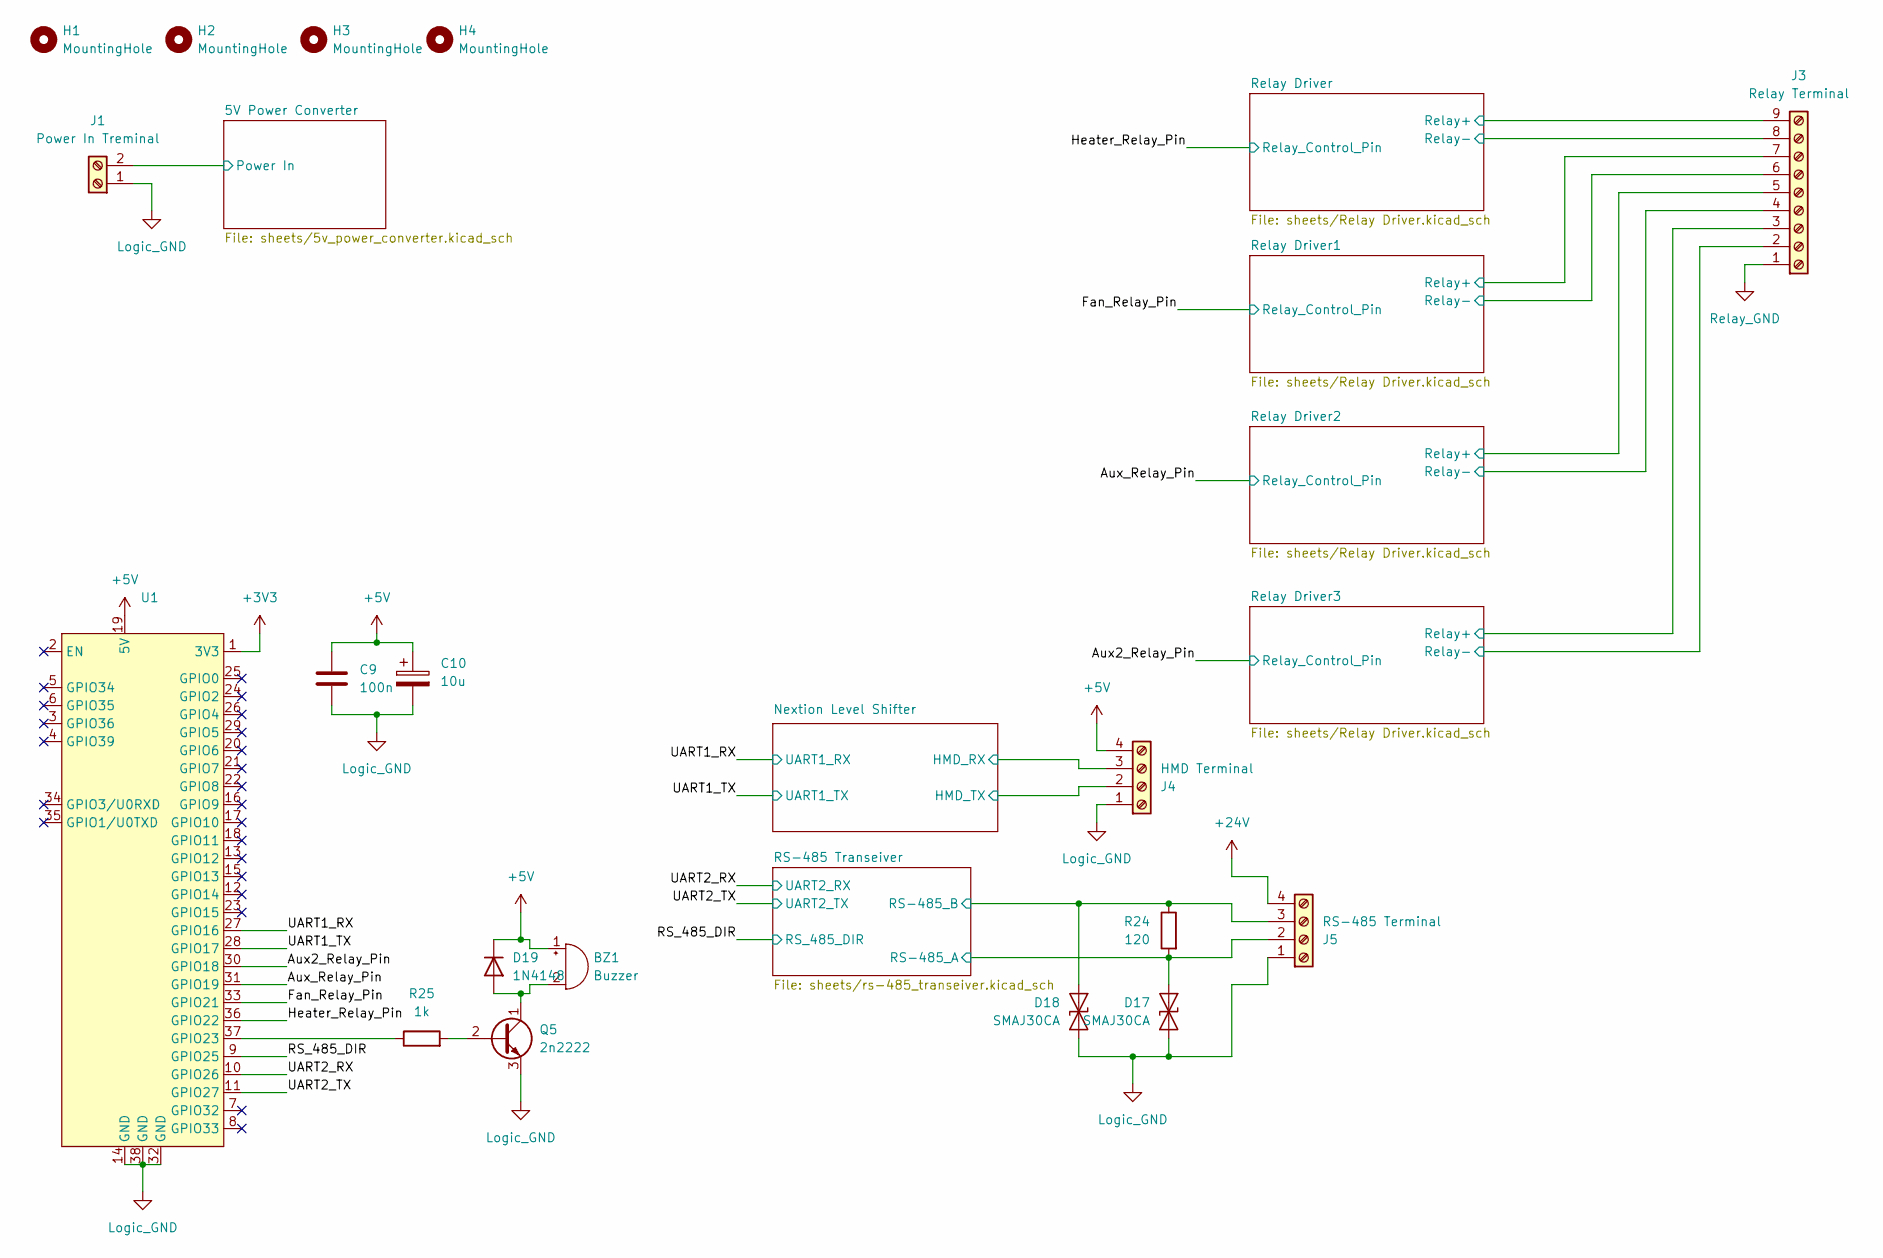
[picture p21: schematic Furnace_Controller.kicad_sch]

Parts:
BZ1: Buzzer; Buzzer_15x7.5RM7.6
C9: 100n; C_0805_2012Metric_Pad1.18x1.45mm_HandSolder
C10: 10u; CP_Radial_D5.0mm_P2.00mm
D17, D18: SMAJ30CA; D_SMA
D19: 1N4148; D_DO-35_SOD27_P7.62mm_Horizontal
H1, H2, H3, H4: MountingHole; MountingHole_5.3mm_M5
J1: Power In Treminal; TerminalBlock_MaiXu_MX126-5.0-02P_1x02_P5.00mm
J3: Relay Terminal; TerminalBlock_MaiXu_MX126-5.0-09P_1x09_P5.00mm
J4: HMD Terminal; TerminalBlock_MaiXu_MX126-5.0-04P_1x04_P5.00mm
J5: RS-485 Terminal; TerminalBlock_MaiXu_MX126-5.0-04P_1x04_P5.00mm
Q5: 2n2222; TO-92_Inline
R24: 120; R_0805_2012Metric_Pad1.20x1.40mm_HandSolder
R25: 1k; R_0805_2012Metric_Pad1.20x1.40mm_HandSolder
U1: ESP32_DevKitc_V4

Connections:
+3V3: U1.1 (3V3); also elsewhere on the board
+5V: BZ1.1 (+), C9.1, C10.1, D19.1 (K), J4.4, U1.19 (5V); also elsewhere on the board
+24V: J3.3, J3.5, J3.7, J3.9, J5.4; also elsewhere on the board
/5V Power Converter/Power In: J1.2; also elsewhere on the board
/Aux2_Relay_Pin: U1.30 (GPIO18); also elsewhere on the board
/Aux_Relay_Pin: U1.31 (GPIO19); also elsewhere on the board
/Fan_Relay_Pin: U1.33 (GPIO21); also elsewhere on the board
/Heater_Relay_Pin: U1.36 (GPIO22); also elsewhere on the board
/Nextion Level Shifter/HMD_RX: J4.3; also elsewhere on the board
/Nextion Level Shifter/HMD_TX: J4.2; also elsewhere on the board
/RS-485 Transeiver/RS-485_A: D17.2 (A2), J5.2, R24.2; also elsewhere on the board
/RS-485 Transeiver/RS-485_B: D18.2 (A2), J5.3, R24.1; also elsewhere on the board
/RS_485_DIR: U1.9 (GPIO25); also elsewhere on the board
/Relay Driver1/Relay-: J3.6; also elsewhere on the board
/Relay Driver2/Relay-: J3.4; also elsewhere on the board
/Relay Driver3/Relay-: J3.2; also elsewhere on the board
/Relay Driver/Relay-: J3.8; also elsewhere on the board
/UART1_RX: U1.27 (GPIO16); also elsewhere on the board
/UART1_TX: U1.28 (GPIO17); also elsewhere on the board
/UART2_RX: U1.10 (GPIO26); also elsewhere on the board
/UART2_TX: U1.11 (GPIO27); also elsewhere on the board
Logic_GND: C9.2, C10.2, D17.1 (A1), D18.1 (A1), J1.1, J4.1, J5.1, Q5.3 (E), U1.14 (GND), U1.32 (GND), U1.38 (GND); also elsewhere on the board
unnamed: BZ1.2 (-), D19.2 (A), Q5.1 (C)
unnamed: Q5.2 (B), R25.2
unnamed: R25.1, U1.37 (GPIO23)
Relay_GND: J3.1; also elsewhere on the board

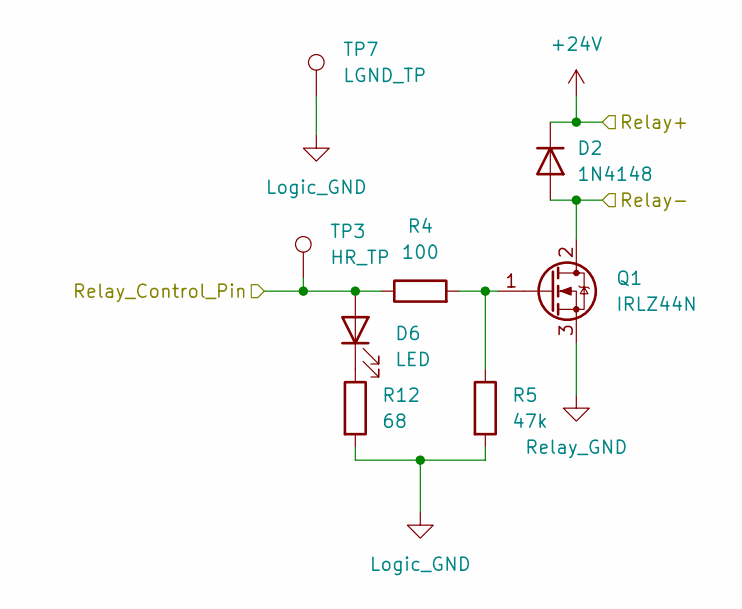
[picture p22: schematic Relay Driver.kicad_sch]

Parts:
D2: 1N4148; D_DO-35_SOD27_P7.62mm_Horizontal
D6: LED; LED_0805_2012Metric
Q1: IRLZ44N; TO-220-3_Vertical
R4: 100; R_0805_2012Metric_Pad1.20x1.40mm_HandSolder
R5: 47k; R_0805_2012Metric_Pad1.20x1.40mm_HandSolder
R12: 68; R_0805_2012Metric_Pad1.20x1.40mm_HandSolder
TP3: HR_TP; TestPoint_Pad_D1.5mm
TP7: LGND_TP; TestPoint_Pad_D1.5mm

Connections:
+24V: D2.1 (K); also elsewhere on the board
/Heater_Relay_Pin: D6.2 (A), R4.1, TP3.1; also elsewhere on the board
/Relay Driver/Relay-: D2.2 (A), Q1.2 (D); also elsewhere on the board
Logic_GND: R5.2, R12.2, TP7.1; also elsewhere on the board
unnamed: D6.1 (K), R12.1
unnamed: Q1.1 (G), R4.2, R5.1
Relay_GND: Q1.3 (S); also elsewhere on the board

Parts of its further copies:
D3, D5, D8: LED; LED_0805_2012Metric
D4, D7, D9: 1N4148; D_DO-35_SOD27_P7.62mm_Horizontal
Q2, Q3, Q4: IRLZ44N; TO-220-3_Vertical
R6, R9, R13: 68; R_0805_2012Metric_Pad1.20x1.40mm_HandSolder
R7, R10, R14: 100; R_0805_2012Metric_Pad1.20x1.40mm_HandSolder
R8, R11, R15: 47k; R_0805_2012Metric_Pad1.20x1.40mm_HandSolder
TP1, TP4, TP6: HR_TP; TestPoint_Pad_D1.5mm
TP5, TP8, TP9: LGND_TP; TestPoint_Pad_D1.5mm

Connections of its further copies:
+24V: D4.1 (K), D7.1 (K), D9.1 (K); also elsewhere on the board
/Aux2_Relay_Pin: D5.2 (A), R10.1, TP6.1; also elsewhere on the board
/Aux_Relay_Pin: D3.2 (A), R7.1, TP4.1; also elsewhere on the board
/Fan_Relay_Pin: D8.2 (A), R14.1, TP1.1; also elsewhere on the board
/Relay Driver1/Relay-: D9.2 (A), Q4.2 (D); also elsewhere on the board
/Relay Driver2/Relay-: D4.2 (A), Q2.2 (D); also elsewhere on the board
/Relay Driver3/Relay-: D7.2 (A), Q3.2 (D); also elsewhere on the board
Logic_GND: R6.2, R8.2, R9.2, R11.2, R13.2, R15.2, TP5.1, TP8.1, TP9.1; also elsewhere on the board
unnamed: D3.1 (K), R6.1
unnamed: D5.1 (K), R9.1
unnamed: D8.1 (K), R13.1
unnamed: Q2.1 (G), R7.2, R8.1
unnamed: Q3.1 (G), R10.2, R11.1
unnamed: Q4.1 (G), R14.2, R15.1
Relay_GND: Q2.3 (S), Q3.3 (S), Q4.3 (S); also elsewhere on the board

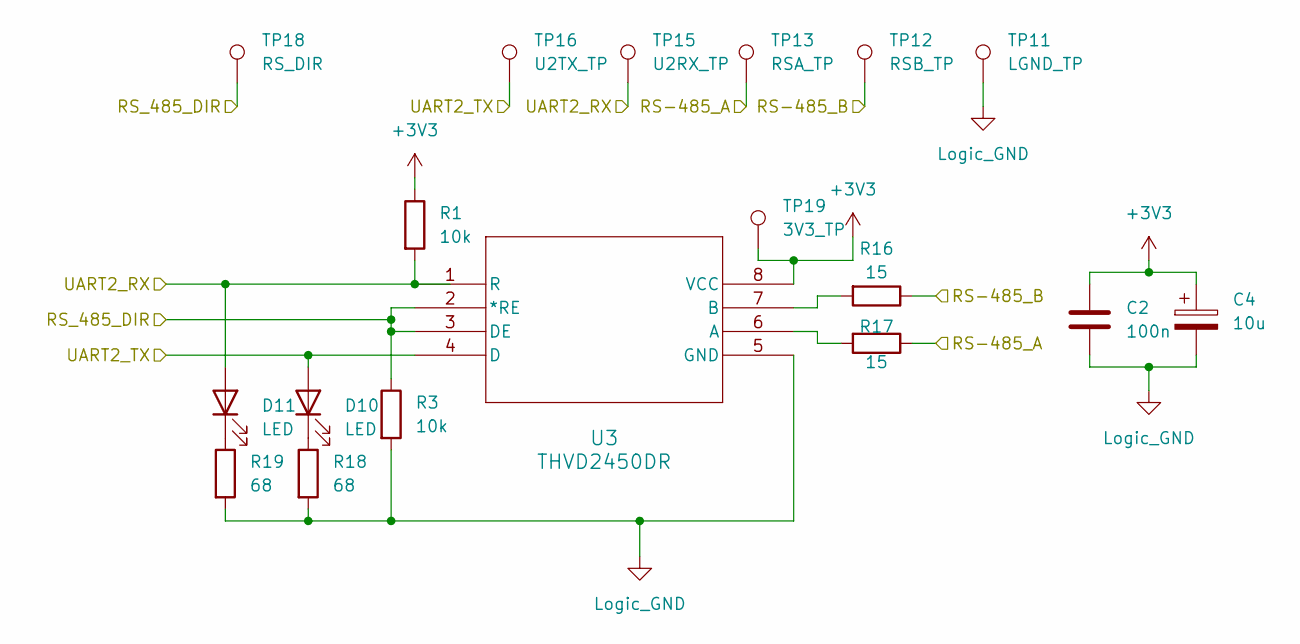
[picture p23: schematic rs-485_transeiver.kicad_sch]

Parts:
C2: 100n; C_0805_2012Metric_Pad1.18x1.45mm_HandSolder
C4: 10u; CP_Radial_D5.0mm_P2.00mm
D10, D11: LED; LED_0805_2012Metric
R1, R3: 10k; R_0805_2012Metric_Pad1.20x1.40mm_HandSolder
R16, R17: 15; R_0805_2012Metric_Pad1.20x1.40mm_HandSolder
R18, R19: 68; R_0805_2012Metric_Pad1.20x1.40mm_HandSolder
TP11: LGND_TP; TestPoint_Pad_D1.5mm
TP12: RSB_TP; TestPoint_Pad_D1.5mm
TP13: RSA_TP; TestPoint_Pad_D1.5mm
TP15: U2RX_TP; TestPoint_Pad_D1.5mm
TP16: U2TX_TP; TestPoint_Pad_D1.5mm
TP18: RS_DIR; TestPoint_Pad_D1.5mm
TP19: 3V3_TP; TestPoint_Pad_D1.5mm
U3: THVD2450DR; SOIC127P600X175-8N

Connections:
+3V3: C2.1, C4.1, R1.1, TP19.1, U3.8 (VCC); also elsewhere on the board
/RS-485 Transeiver/RS-485_A: R17.1, TP13.1; also elsewhere on the board
/RS-485 Transeiver/RS-485_B: R16.1, TP12.1; also elsewhere on the board
/RS_485_DIR: R3.1, TP18.1, U3.2 (*RE), U3.3 (DE); also elsewhere on the board
/UART2_RX: D11.2 (A), R1.2, TP15.1, U3.1 (R); also elsewhere on the board
/UART2_TX: D10.2 (A), TP16.1, U3.4 (D); also elsewhere on the board
Logic_GND: C2.2, C4.2, R3.2, R18.2, R19.2, TP11.1, U3.5 (GND); also elsewhere on the board
unnamed: D10.1 (K), R18.1
unnamed: D11.1 (K), R19.1
unnamed: R17.2, U3.6 (A)
unnamed: R16.2, U3.7 (B)

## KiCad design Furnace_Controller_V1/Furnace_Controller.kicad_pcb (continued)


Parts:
C1: 220u; CP_Radial_D12.5mm_P5.00mm
C3: 47u; CP_Radial_D8.0mm_P2.50mm
D1, D16: 1N5822; D_DO-201AD_P15.24mm_Horizontal
F2: 3588; Mouser Part Number 534-3588
L1: 33u; SRR1260-150M
TP2: PGND_TP; TestPoint_Pad_D1.5mm
TP14: 5V_TP; TestPoint_Pad_D1.5mm
TP26: 24V_TP; TestPoint_Pad_D1.5mm
U2: LM2596S-5; TO-263-5_TabPin3
U6: TVS3300DRV; WSON-6-1EP_2x2mm_P0.65mm_EP1x1.6mm

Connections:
+5V: C1.1, L1.2, TP14.1, U2.4 (FB); also elsewhere on the board
+24V: C3.1, F2.2, F2.3, TP26.1, U2.1 (VIN), U6.4 (IN), U6.5 (IN), U6.6 (IN); also elsewhere on the board
/5V Power Converter/Power In: D16.2 (A); also elsewhere on the board
Logic_GND: C1.2, C3.2, D1.2 (A), TP2.1, U2.3 (GND), U2.5 (~ON/OFF), U6.1 (GND), U6.2 (GND), U6.3 (GND), U6.7 (GND); also elsewhere on the board
unnamed: D1.1 (K), L1.1, U2.2 (OUT)
unnamed: D16.1 (K), F2.1, F2.4


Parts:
C5, C6, C7, C8: 100n; C_0805_2012Metric_Pad1.18x1.45mm_HandSolder
D12, D13, D14, D15: LED; LED_0805_2012Metric
R20, R23: 330; R_0805_2012Metric_Pad1.20x1.40mm_HandSolder
R21, R22: 68; R_0805_2012Metric_Pad1.20x1.40mm_HandSolder
TP20: 5V_TP; TestPoint_Pad_D1.5mm
TP21: 3V3_TP; TestPoint_Pad_D1.5mm
TP22: U1TX_TP; TestPoint_Pad_D1.5mm
TP23: U1RX_TP; TestPoint_Pad_D1.5mm
TP24: HMDTX_TP; TestPoint_Pad_D1.5mm
TP25: HMDRX_TP; TestPoint_Pad_D1.5mm
U4, U5: TXU0101DBVR; SOT95P280X145-6N

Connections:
+3V3: C5.1, C8.1, TP21.1, U4.5 (OE), U4.6 (VCCB), U5.1 (VCCA); also elsewhere on the board
+5V: C6.1, C7.1, TP20.1, U4.1 (VCCA), U5.5 (OE), U5.6 (VCCB); also elsewhere on the board
/Nextion Level Shifter/HMD_RX: D15.2 (A), TP25.1, U5.4 (BY); also elsewhere on the board
/Nextion Level Shifter/HMD_TX: D12.2 (A), TP24.1, U4.3 (A); also elsewhere on the board
/UART1_RX: D13.2 (A), TP23.1, U4.4 (BY); also elsewhere on the board
/UART1_TX: D14.2 (A), TP22.1, U5.3 (A); also elsewhere on the board
Logic_GND: C5.2, C6.2, C7.2, C8.2, R20.2, R21.2, R22.2, R23.2, U4.2 (GND), U5.2 (GND); also elsewhere on the board
unnamed: D12.1 (K), R20.1
unnamed: D13.1 (K), R21.1
unnamed: D14.1 (K), R22.1
unnamed: D15.1 (K), R23.1


Board: 2 copper layers, 149.0 x 141.0 mm, 99 parts (0 on the bottom side), 44 nets.

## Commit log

2026-04-04 Initial commit V1
    [5v_power_converter.kicad_sch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]
2026-04-04 Duplicate V1 and prepare for V2 dev
    [5v_power_converter.kicad_sch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]
2026-04-10 V2 dev
    [1663969.PcbLib, 1663969.SchLib, 1663969.psm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]
2026-06-11 Start v2
    [Furnace_Controller-B_Mask.gbr, Furnace_Controller-B_Paste.gbr, Furnace_Controller-B_Silkscreen.gbr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]
2026-09-10 Organize PCB revisions and correct TI footprints
    [5v_power_converter.kicad_sch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]
2026-09-10 Normalize 3.3V net names
    [Furnace_Controller.kicad_pcb, Furnace_Controller.kicad_sch, ethernet_module.kicad_sch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]
2026-09-29 Save current KiCad project changes
